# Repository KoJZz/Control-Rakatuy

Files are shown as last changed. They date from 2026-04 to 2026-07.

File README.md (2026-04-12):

# Control-Rakatuy

Repository Control Rakata

## Struktur Folder

* **.git/**: Git configuration (Do not modify)
* **Hardware/**: KiCad PCB layout and schematic files. Nanti buat folder baru aja per project
* **Firmware/**: Firmware yang dipake
* **Docs/**: Documentation
* **Exports/**: (Gerbers, BOM, and PDF schematics)
* **testing/**: ngetes repo

---

### Cloning to a New Machine
To pull this repository into a new local folder:
```bash
git clone https://github.com/KoJZz/Control-Rakatuy

```
### Upload konten baru
```bash
git pull origin main # pull updatean terbaru dari repo
git add . # add file terbaru yang udah dibuat
git commit -m "Update: [Component Name] - Added power stage layout" # commiting
git push origin main # push ke repo

```

### Video tutorial version control
https://www.youtube.com/watch?v=YCKeqBlQyJQ

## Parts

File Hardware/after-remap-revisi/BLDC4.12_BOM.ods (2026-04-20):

Part | Value | Package | Description | Qty | Place (YES/NO) | Distributor | Order Number | Comment
U1 |  | LQFP-64 | STM32F4 MCU | 1 | YES | MOUSER | 511-STM32F405RGT6
U2 |  | SOT-223-3 | VREG | 1 | YES | MOUSER | 579-TC2117-3.3VDBTR
U3 |  | HTSSOP-56-PP | MOSFET Driver | 1 | YES | MOUSER | 595-DRV8302DCA
U401 |  | SOIC-8 | CAN Transceiver | 1 | YES | MOUSER | 595-SN65HVD232DR
R1 |  | SM0603 | NTC resistor (temp sensor) | 1 | YES | MOUSER | 81-NCP18XH103F03RB
L1 |  | inductor_smd_8x5mm | Power Inductor | 1 | YES | MOUSER | 652-SDR0805-220ML
X1 |  | USB-UX60R-MB-5ST | Mini-USB | 1 | YES | MOUSER | 798-UX60R-MB-5ST
X2 | 8MHz | Crystal_5x3mm | Crystal 8MHz, 10PPM | 1 | YES | MOUSER | 815-ABM3B-8.0-10-1UT
Q1-Q6 | 60V 240A | D2PAK-7 | MOSFET 60V 240A | 6 | YES | MOUSER | 942-IRFS7530TRL7PP
R53,R54 | 1mOhm | WSLP2726 | Shunt 1mOhm | 2 | YES | MOUSER | 71-WSLP27261L000FEA
D5 | 5V | DO-214AC | TVS diode 5V | 1 | YES | MOUSER | 576-SMAJ5.0A
D4 | 60V 2A | DO-214AA(SMB) | Shottky 60V 2A | 1 | YES | MOUSER | 771-PMEG6020ER-115 | Voltage and current important
C25,C33 | 100uF, 6.3V | c_tant_B | CAP 100u, 6.3V | 2 | YES | MOUSER | 581-TPSB107K006R0400 | Voltage important
C1,C8,C9,C39,C40,C43,C44,C49 | 10uF 50V | SMD1206 | CAP 10u, 50V, 1206 | 8 | YES | MOUSER | 963-UMK316BBJ106ML-T | Voltage important
C37,C51 | 15uF, 100V | SMD-2220 | CAP 15u, 100V, 2220 | 2 | YES | MOUSER | 810-CGA9P3X7S2A156M | Voltage important
C2,C3,C27,C32 | 100nF, 50V | SMD-0603 | CAP 100n, 50V, 0603 | 4 | YES | MOUSER | 581-06035C104JAT2A | Voltage important
C28,C29,C30 | 220nF,25V | SMD-0603 | CAP 220n, 25V, 0603 | 3 | YES | MOUSER | 963-TMK107B7224KA-T | Voltage important
C24,C10,C11,C12,C13,C14,C16,C17,C18,C20,C23,C26,C31,C35,C41,C52,C401 | 2.2uF, 16V | SMD-0603 | CAP 2.2u, 16V, 0603 | 17 | YES | MOUSER | 810-C1608X5R1C225M | Voltage important
P3 |  | MICRO_JST_7 | Micro-JST 7PIN 2mm | 1 | YES | FARNELL | 9491864 | Can be found on ebay (http://www.ebay.com/sch/i.html?_odkw=jst+6+pin+2.0&_osacat=0&_from=R40&_nkw=jst+7+pin+2.0&_sacat=0)
P1,P2 |  | MICRO_JST_6 | Micro-JST 6PIN 2mm | 2 | YES | FARNELL | 9492453 | Can be found on ebay (http://www.ebay.com/sch/i.html?_odkw=jst+7+pin+2.0&_osacat=0&_from=R40&_nkw=jst+6+pin+2.0&_sacat=0)
P101 |  | MICRO_JST_4 | Micro-JST 4PIN 2mm | 1 | YES | FARNELL | 9492437 | Can be found on ebay (http://www.ebay.com/sch/i.html?_odkw=jst+6+pin+2.0&_osacat=0&_from=R40&_nkw=jst+4+pin+2.0&_sacat=0)
C4-C7 | 4.7nF, 50V | SMD-0603 | CAP 4.7n, 50V, 0603 | 4 | YES | MOUSER | 81-GRM39X472J50D
C34, C36 | 2.2nF, 50V | SMD-0603 | CAP 2.2n, 50V, 0603 | 2 | YES | MOUSER | 81-GRM39X222J50D
C15,C38 | 15pF, 100V | SMD-0603 | CAP 15p, 100V, 0603 | 2 | YES | MOUSER | 81-GRM1885C2A150JA01
C19 | 120pF, 50V | SMD-0603 | CAP 120p, 50V, 0603 | 1 | YES | MOUSER | 81-GRM39C121J50
C21 | 6.8nF, 50V | SMD-0603 | CAP 6.8n, 50V, 0603 | 1 | YES | MOUSER | 81-GRM18R71H682KA01J
C22 | 22nF, 50V | SMD-0603 | CAP 22n, 50V, 0603 | 1 | YES | MOUSER | 81-GRM18F51H223ZA01D
D1 |  | SMD-0603 | LED Green, 0603 | 1 | YES | MOUSER | 859-LTST-C191KGKT
D2 |  | SMD-0603 | LED Red, 0603 | 1 | YES | MOUSER | 859-LTST-C191KRKT
D3 |  | SMD-0603 | LED Blue, 0603 | 1 | YES | MOUSER | 720-LBQ39GN1P1351
R28,R29,R34,R35,R42,R43 | 4.7ohm | SMD-0603 | R 4.7ohm, 0603 | 6 | YES | MOUSER | 660-RK73H1JTTD4R70F
R37,R38,R48-R51,R401 | 100ohm | SMD-0603 | R 100ohm, 0603 | 7 | YES | MOUSER | 660-RK73H1JTTD1000F
R4,R5,R11,R12,R13,R22,R24,R27,R33 | 2.2kOhm | SMD-0603 | R 2.2k, 0603 | 9 | YES | MOUSER | 660-RK73H1JTTD2201F
R18 | 3.3kOhm | SMD-0603 | R 3.3k, 0603 | 1 | YES | MOUSER | 660-RK73H1JTTD3301F
R2,R7,R8,R9,R10,R20,R402 | 10kOhm | SMD-0603 | R 10k, 0603 | 7 | YES | MOUSER | 660-RK73H1JTTD1002F
R19 | 15kOhm | SMD-0603 | R 15k, 0603 | 1 | YES | MOUSER | 660-RK73H1JTTD1502F
R17 | 18kOhm | SMD-0603 | R 18k, 0603 | 1 | YES | MOUSER | 660-RK73H1JTTD1802F
R3,R23,R26,R30,R32,R36,R46 | 39kOhm | SMD-0603 | R 39k, 0603 | 7 | YES | MOUSER | 667-ERJ-3EKF3902V
R21 | 220kOhm | SMD-0603 | R 220k, 0603 | 1 | YES | MOUSER | 660-RK73H1JTTD2203F
R25 | 1MOhm | SMD-0603 | R 1M, 0603 | 1 | YES | MOUSER | 660-RK73H1JTTD1004F
R103, R104 | 22ohm | SMD-0603 | R 22R, 0603 | 2 | YES | MOUSER | 660-RK73H1JTTD22R0F
R6 |  |  |  | 0 | NO |  |  | Do not mount
1PIN,1PIN |  |  |  | 0 | NO |  |  | Do not mount
K1 |  |  |  | 0 | NO |  |  | Do not mount
P5,P5,P6,P7,P9 |  |  |  | 0 | NO |  |  | Do not mount
G*** |  |  |  | 0 | NO |  |  | Do not mount

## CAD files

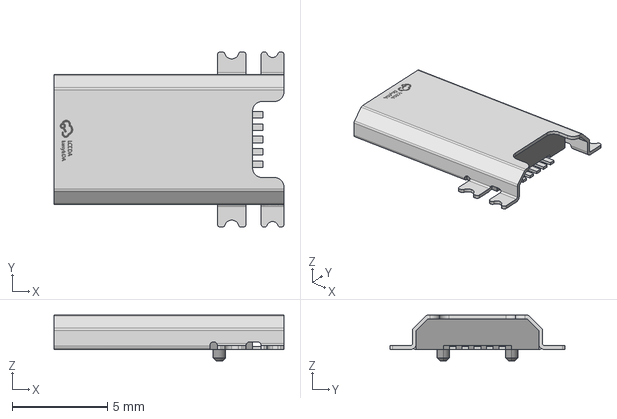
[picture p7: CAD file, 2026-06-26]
Hardware/after-remap-revisi/EASYEDA_MODELS/MICRO-USB-SMD_MICROUSB-5P-M.step
12.1 x 9.23 x 2.40 mm

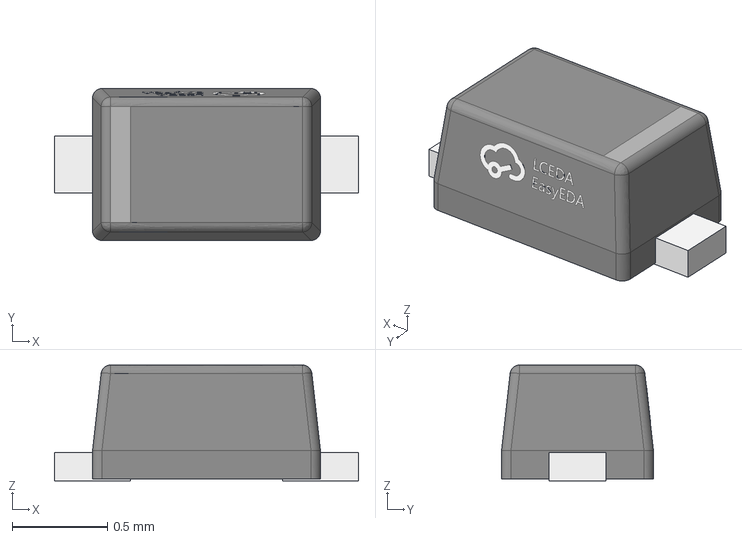
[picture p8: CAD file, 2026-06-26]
Hardware/after-remap-revisi/EASYEDA_MODELS/SOD-523F_L1.2-W0.8-H0.6-LS1.6.step
1.60 x 0.8 x 0.61 mm

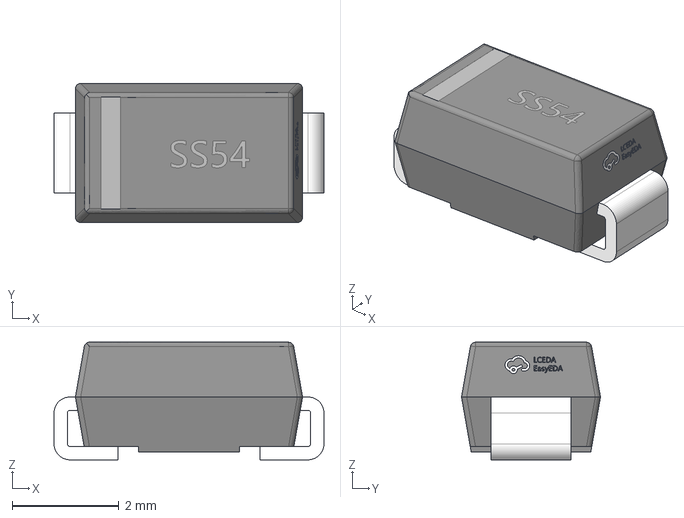
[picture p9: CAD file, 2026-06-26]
Hardware/after-remap-revisi/EASYEDA_MODELS/SMA_L4.2-W2.6-LS5.1-RD.step
5.05 x 2.60 x 2.20 mm

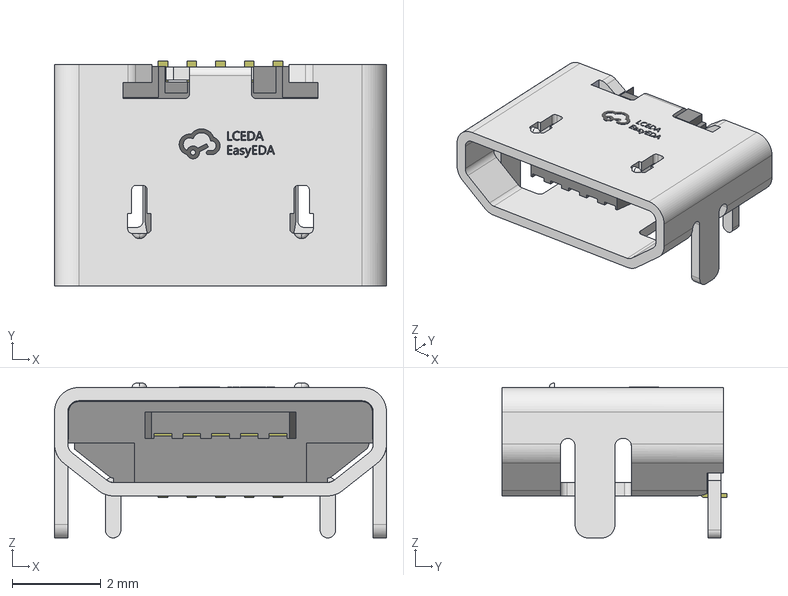
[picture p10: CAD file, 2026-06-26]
Hardware/after-remap-revisi/EASYEDA_MODELS/MICRO-USB-SMD_HX-USB-MICRO-XNJ-JB.step
7.50 x 5.08 x 3.50 mm

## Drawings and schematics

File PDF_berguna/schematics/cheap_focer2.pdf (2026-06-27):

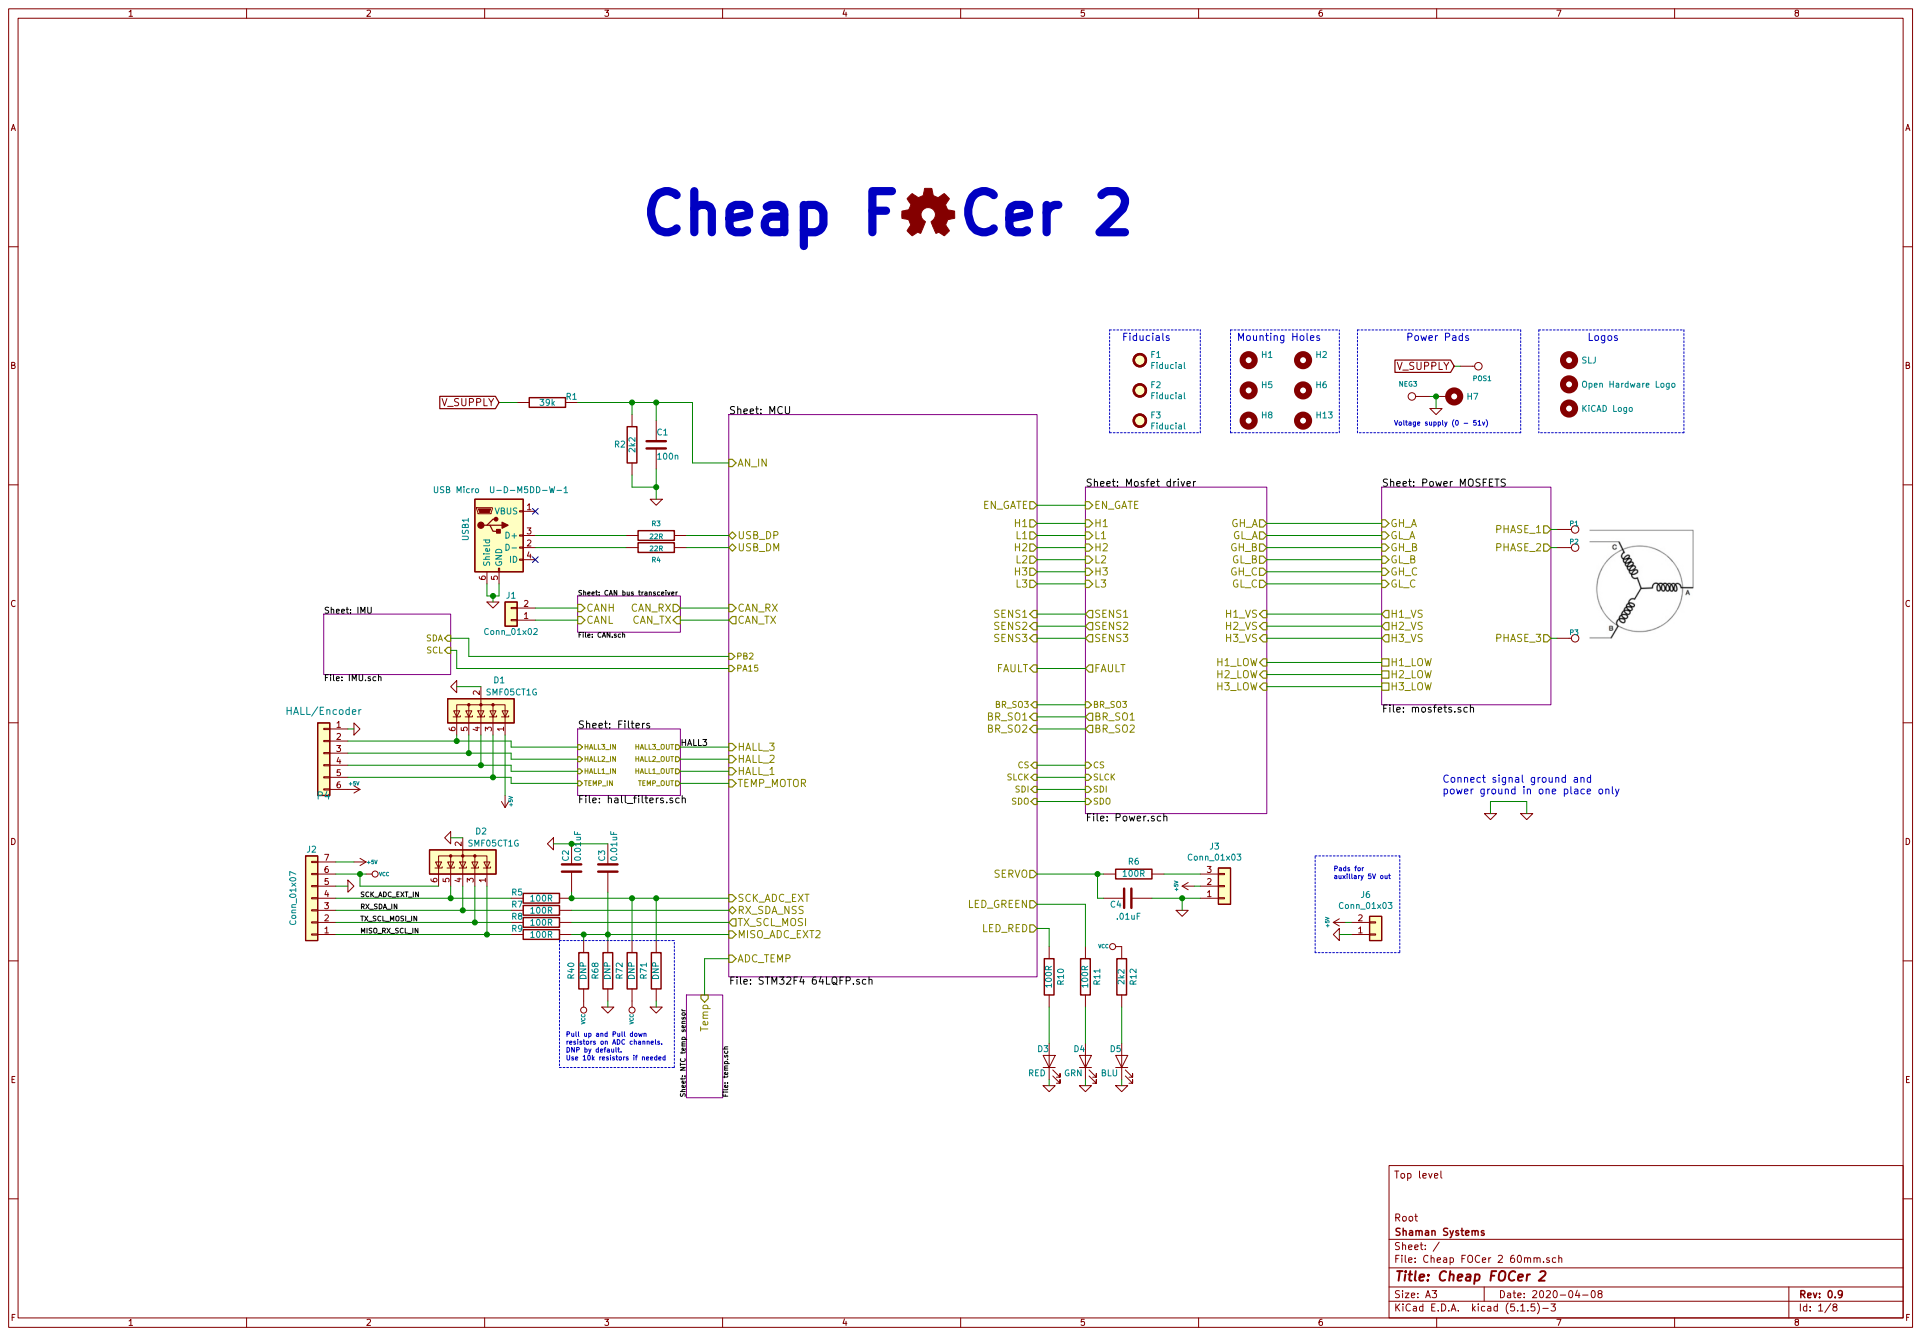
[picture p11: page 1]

power ground in one place only

Pull up and Pull down resistors on ADC channels. DNP by default. Use 10k resistors if needed

File: Cheap FOCer 2 60mm.sch Sheet: / Shaman Systems Root Top level

Id: 1/8 Title: Cheap FOCer 2

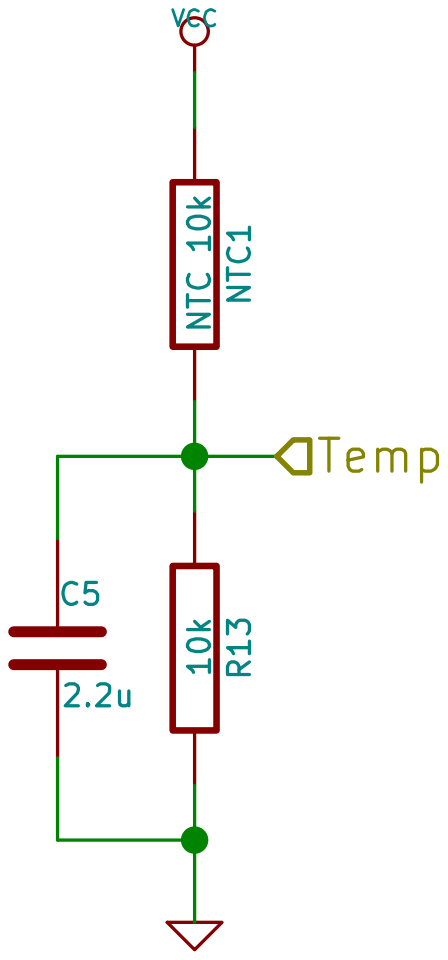
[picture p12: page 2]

Shaman Systems Root Top level 10k R13 C5

Sheet: /NTC temp sensor/
File: temp.sch
Id: 2/8 Title: Cheap FOCer 2

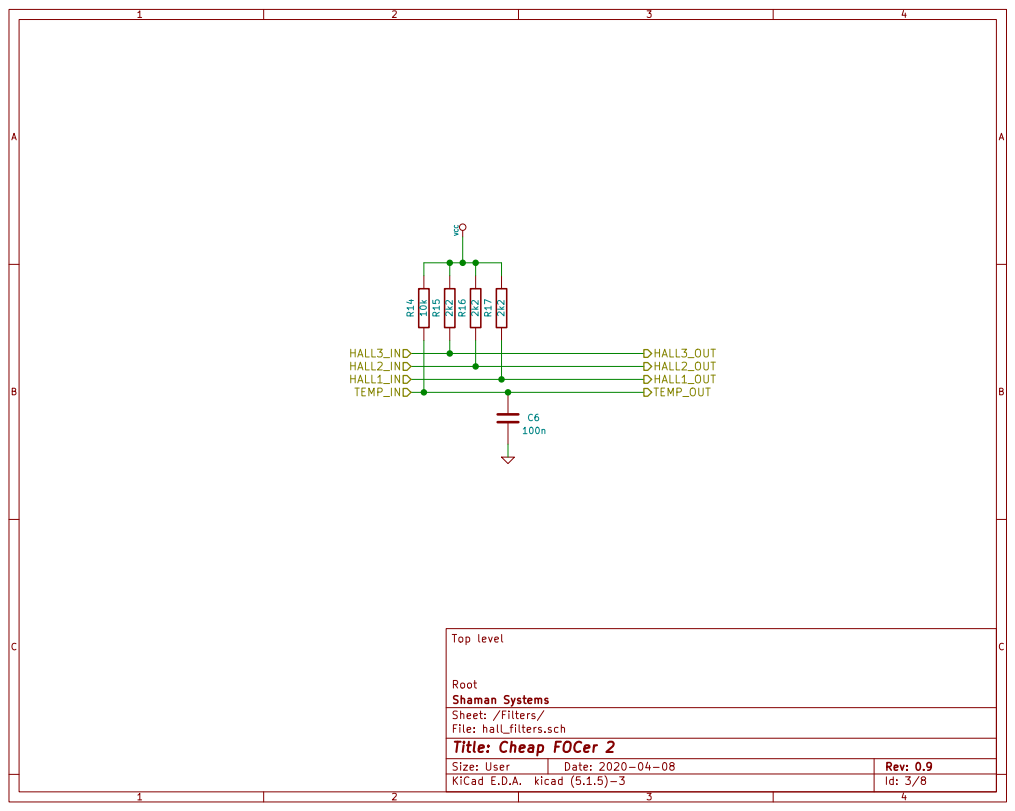
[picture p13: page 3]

Id: 3/8 Title: Cheap FOCer 2

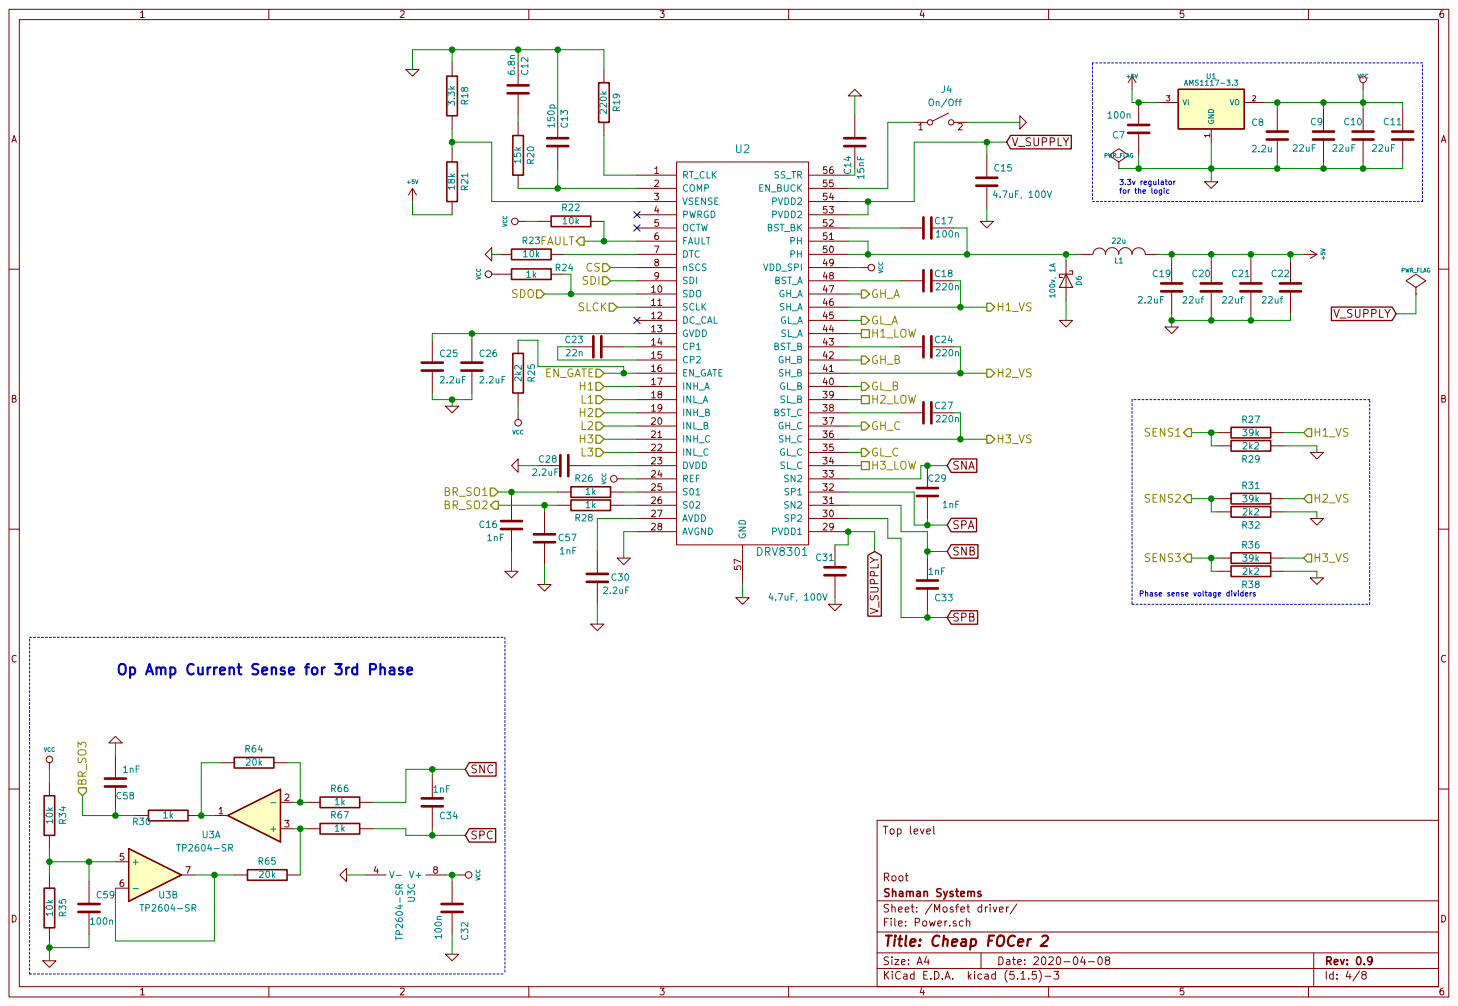
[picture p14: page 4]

for the logic Phase sense voltage dividers Op Amp Current Sense for 3rd Phase

File: Power.sch Sheet: /Mosfet driver/ Shaman Systems Root Top level VCC R67

Id: 4/8 Title: Cheap FOCer 2

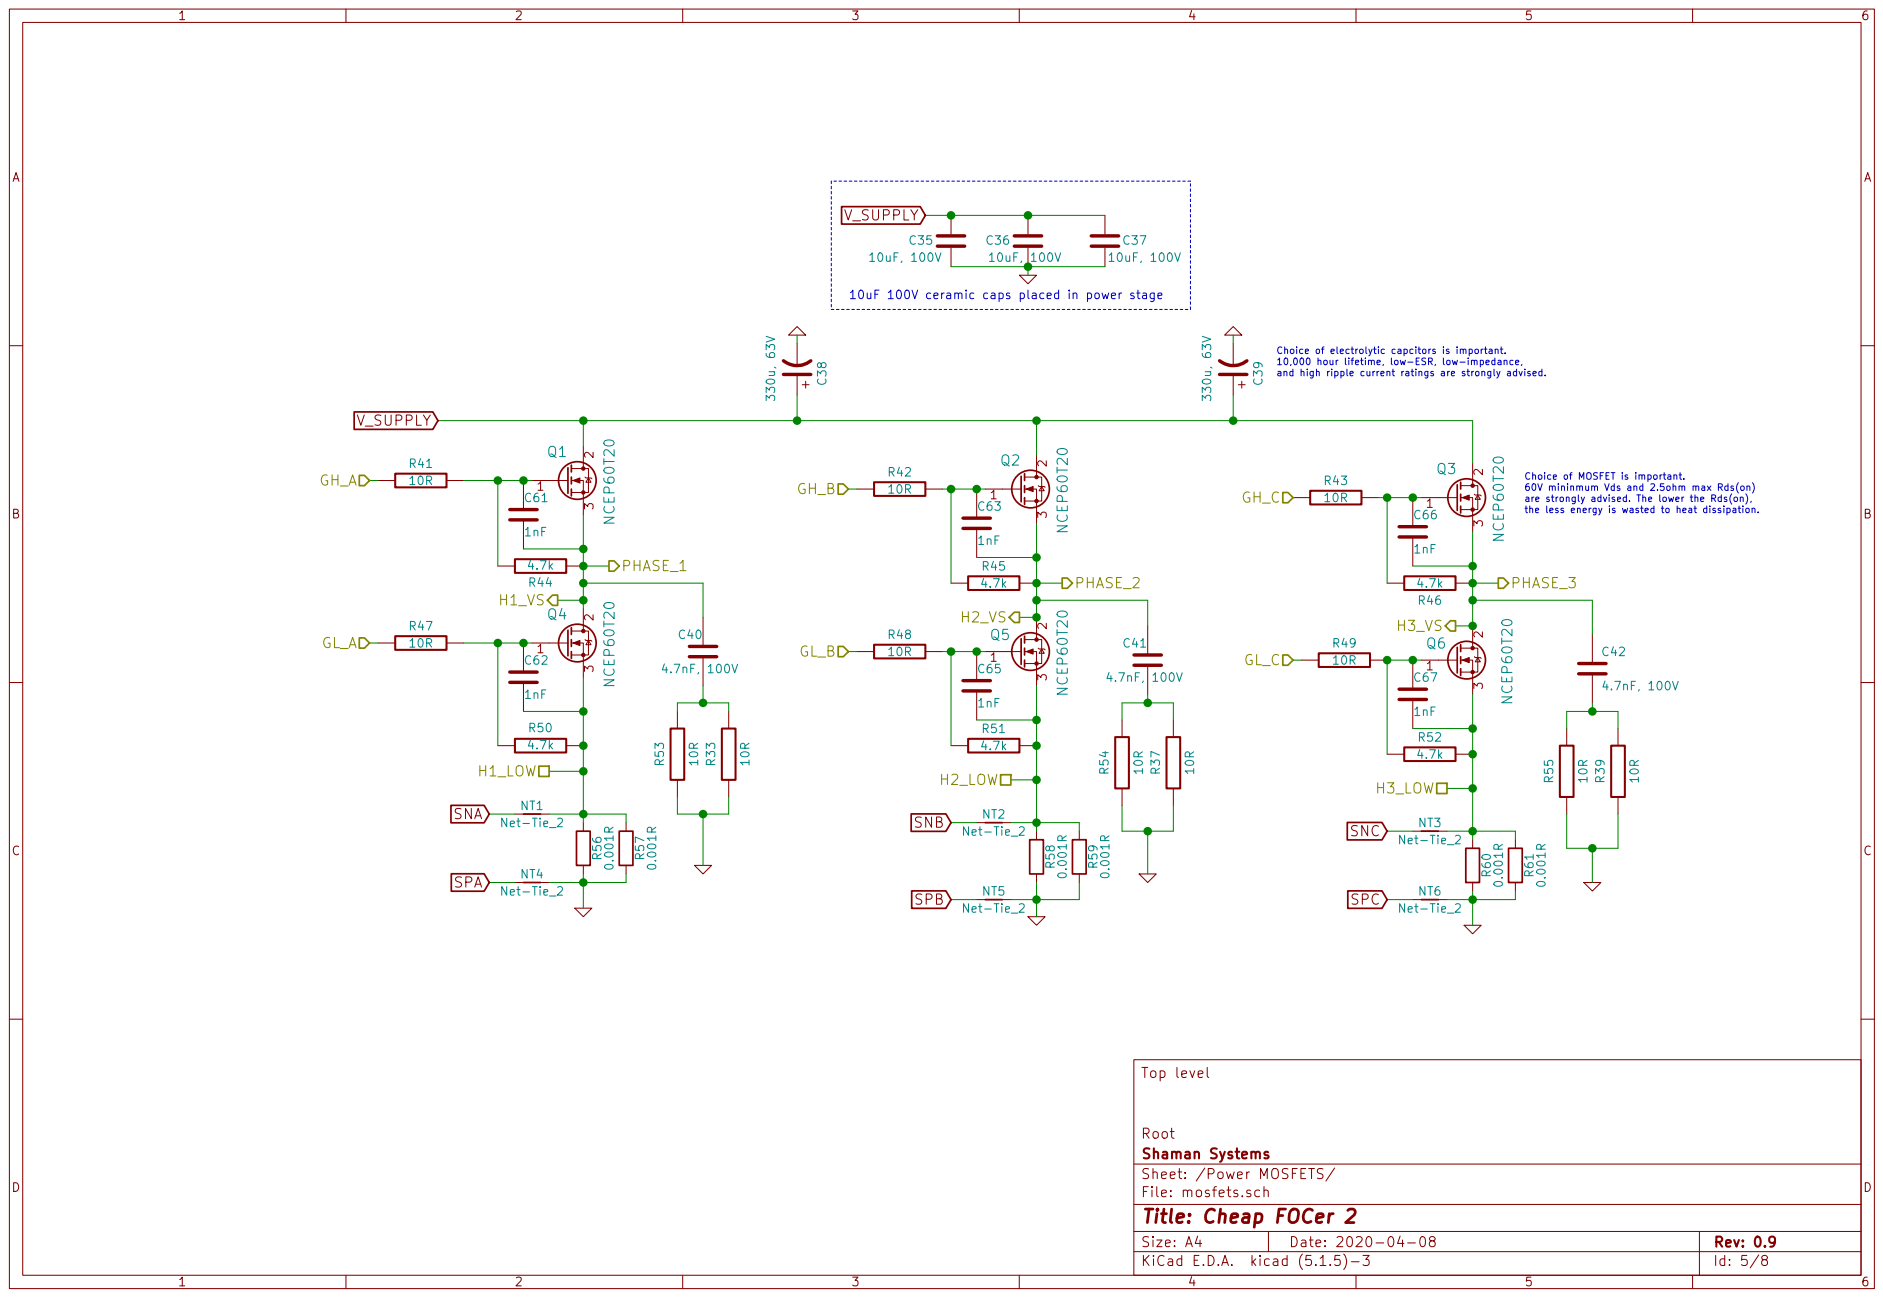
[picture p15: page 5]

the less energy is wasted to heat dissipation.

Id: 5/8 Title: Cheap FOCer 2

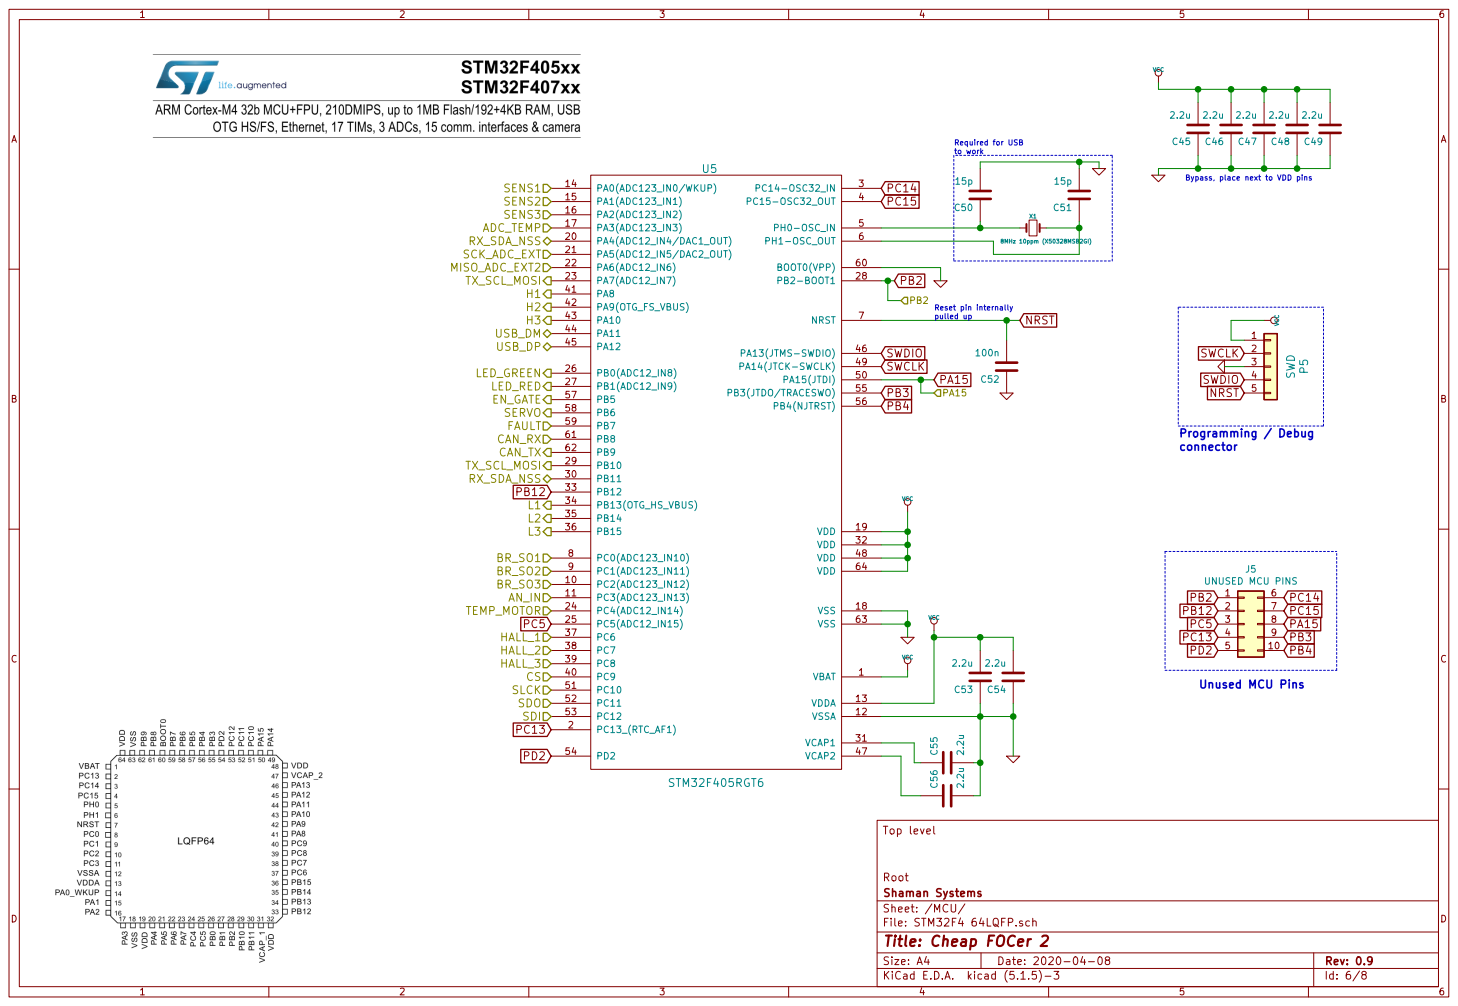
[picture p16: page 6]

Bypass, place next to VDD pins Required for USB

connector Reset pin internally pulled up

Id: 6/8 Title: Cheap FOCer 2

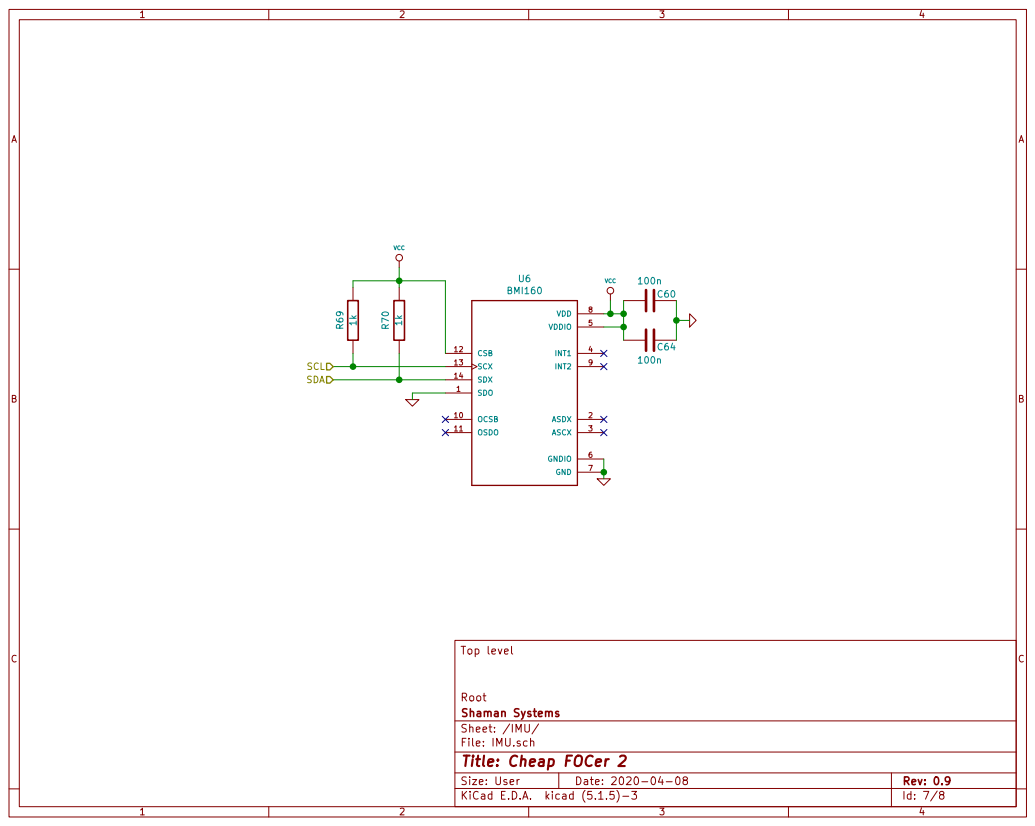
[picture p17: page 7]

Id: 7/8 Title: Cheap FOCer 2

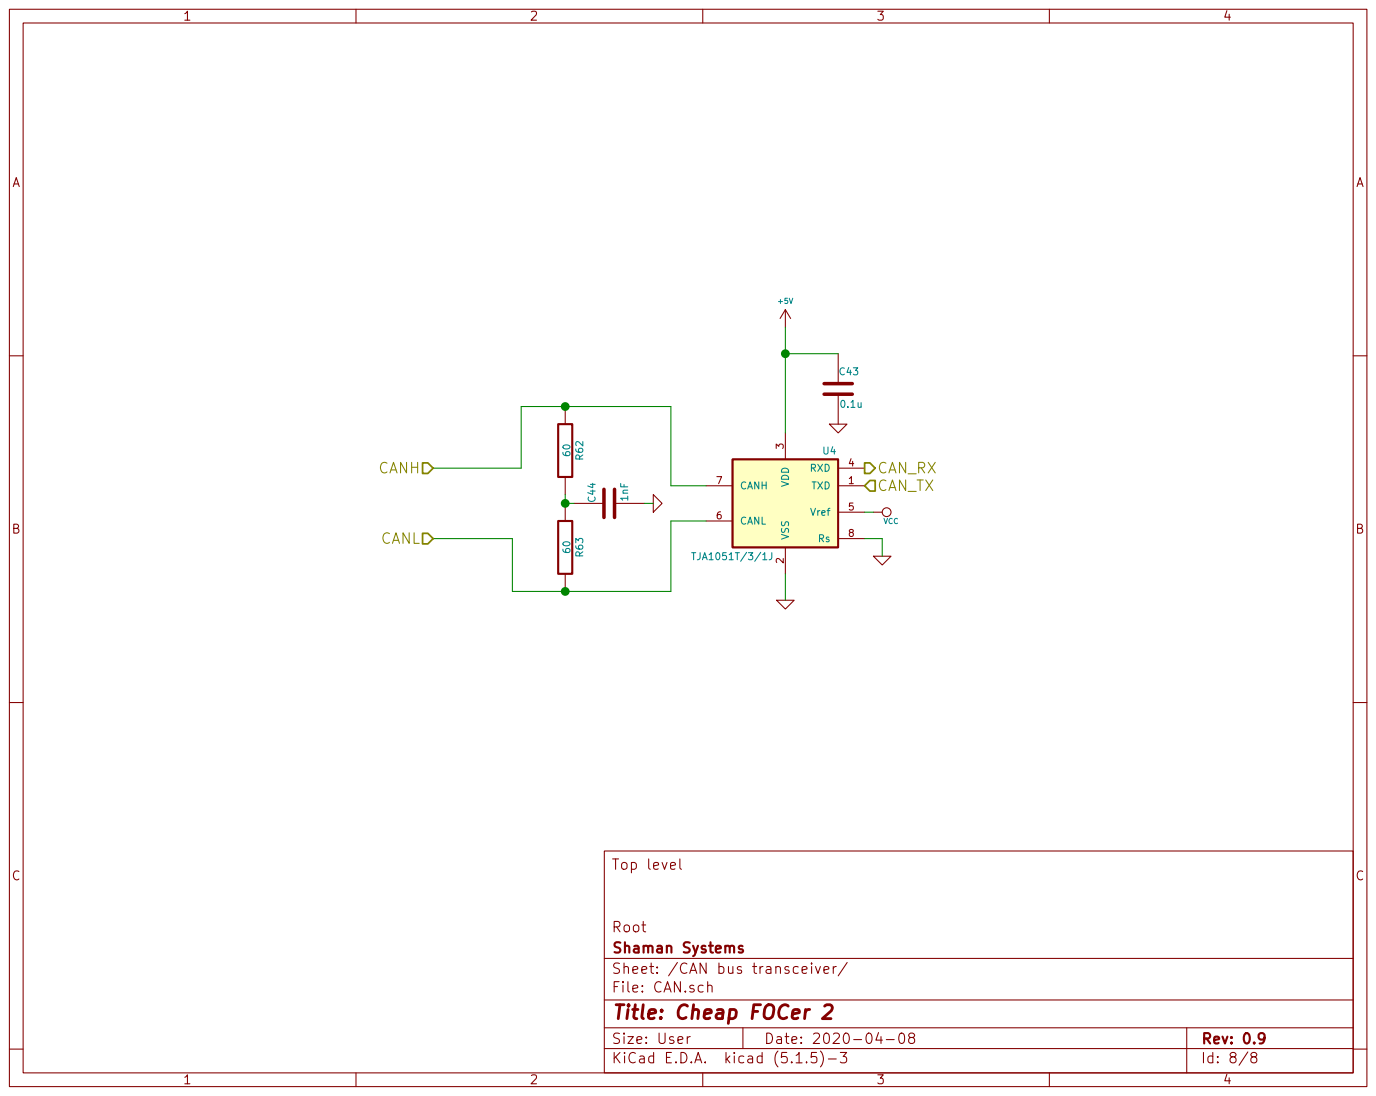
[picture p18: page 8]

3 RXD 4 Vref 5 CANL 6 CANH 7 Rs 8 U4 TJA1051T/3/1J CAN_RX

Id: 8/8 Title: Cheap FOCer 2

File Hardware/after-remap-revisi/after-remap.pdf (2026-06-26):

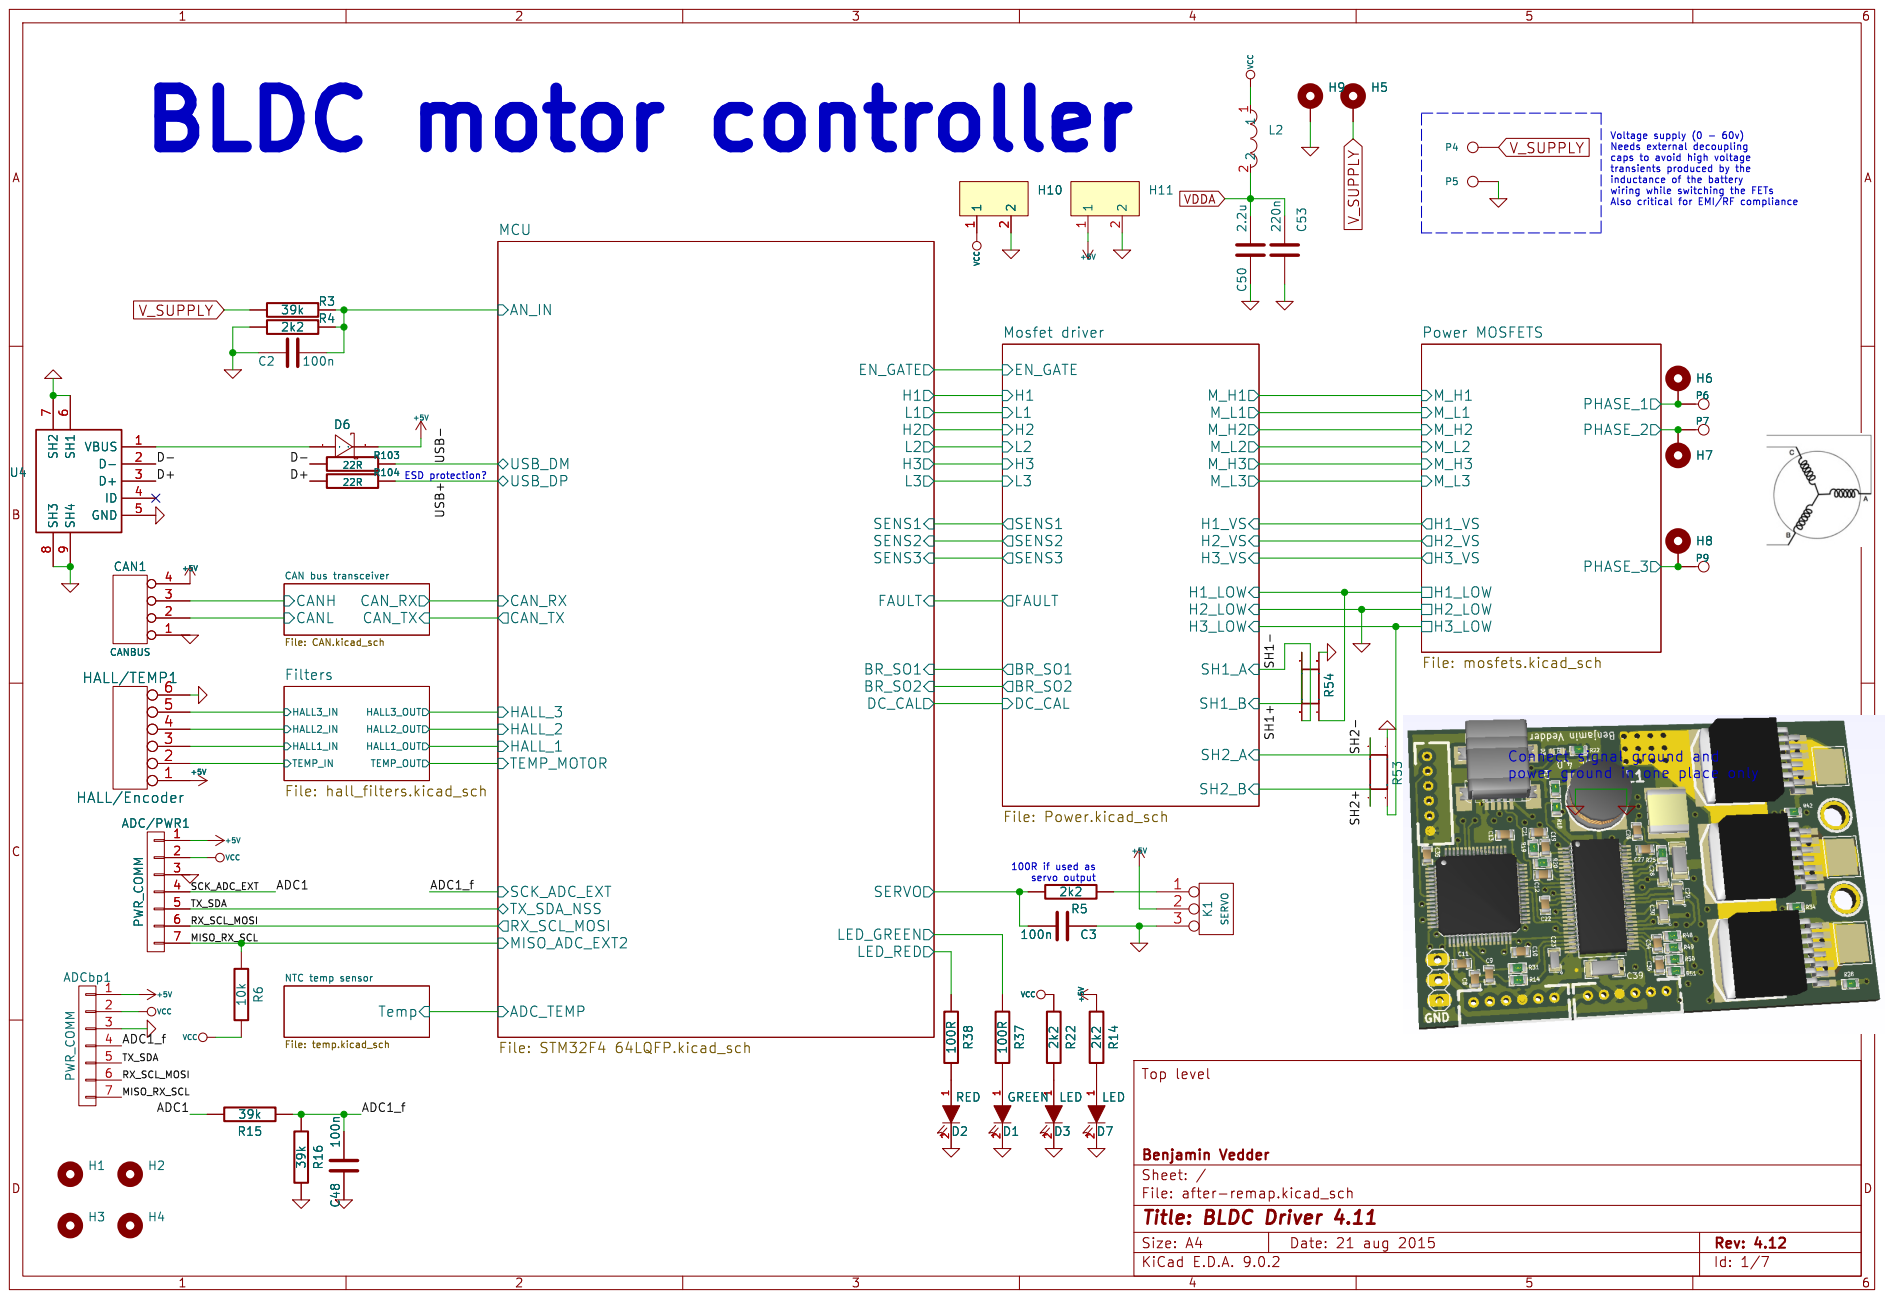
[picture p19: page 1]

SH2_B Mosfet driver File: Power.kicad_sch

caps to avoid high voltage

power ground in one place only

Id: 1/7 Title: BLDC Driver 4.11

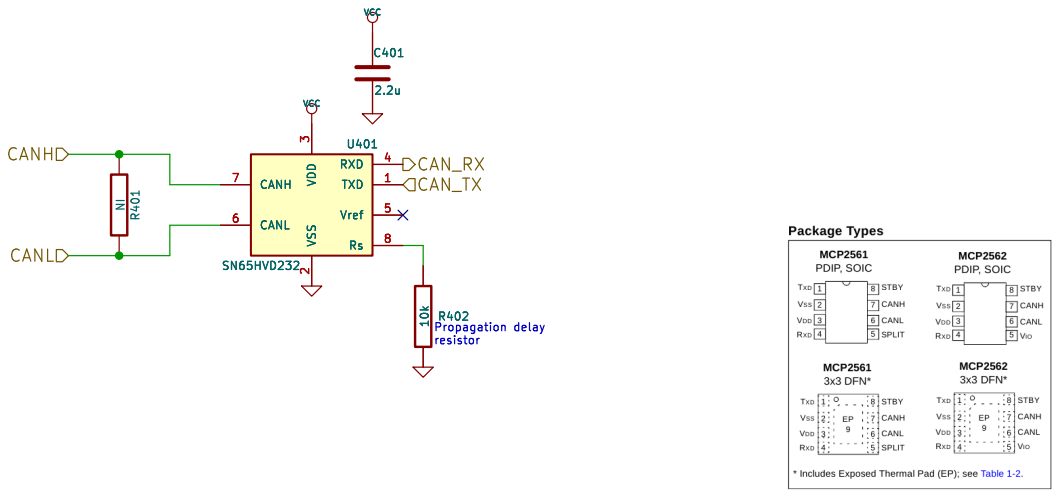
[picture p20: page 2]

Id: 2/7 Title: BLDC Driver 4.11

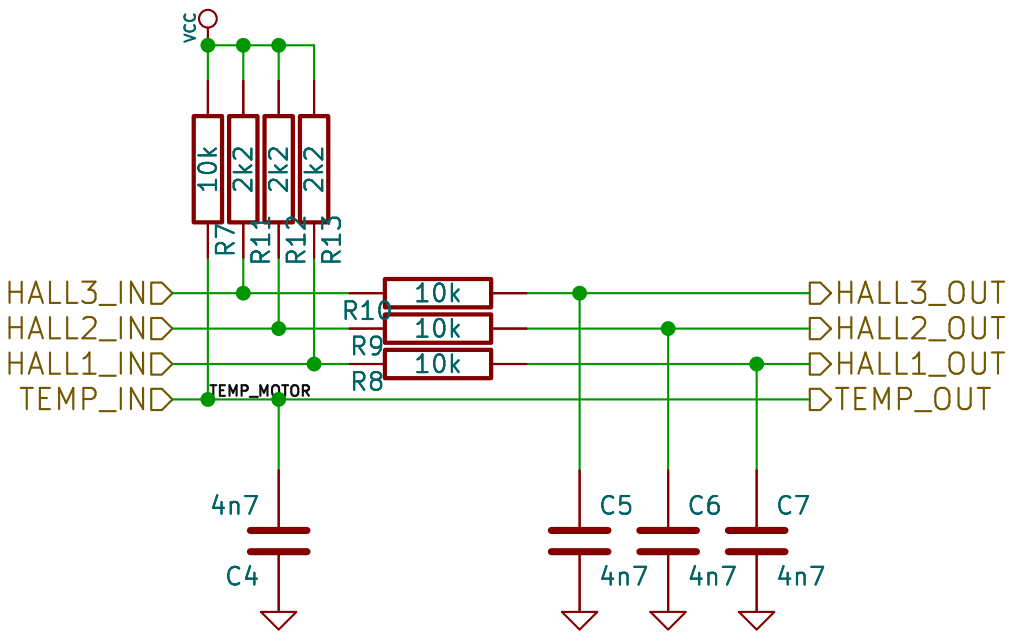
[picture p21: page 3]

File: hall_filters.kicad_sch Sheet: /Filters/ Benjamin Vedder C7

Id: 3/7 Title: BLDC Driver 4.11

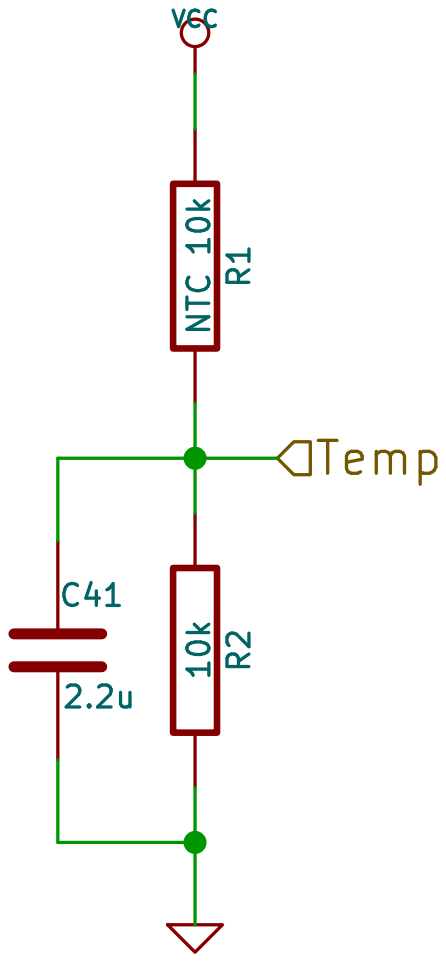
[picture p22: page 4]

File: temp.kicad_sch Sheet: /NTC temp sensor/ Benjamin Vedder R1 NTC 10k VCC10k R2 C41

Id: 4/7 Title: BLDC Driver 4.11


Bypass, place next to VDD pins Required for USB

connector Reset pin internally pulled up C32

Id: 5/7 Title: BLDC Driver 4.11


voltage at each phase

Id: 6/7 Title: BLDC Driver 4.11


Id: 7/7 Title: BLDC Driver 4.11

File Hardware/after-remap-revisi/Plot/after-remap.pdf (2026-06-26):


SH2_B Mosfet driver File: Power.kicad_sch

caps to avoid high voltage

CAN bus transceiver File: CAN.kicad_sch HALL3_IN
CANH
CANL

power ground in one place only R54

Id: 1/7 Title: BLDC Driver 4.11


Id: 2/7 Title: BLDC Driver 4.11


File: hall_filters.kicad_sch Sheet: /Filters/ Benjamin Vedder C6

Id: 3/7 Title: BLDC Driver 4.11


File: temp.kicad_sch Sheet: /NTC temp sensor/ Benjamin Vedder R1 NTC 10k VCC10k R2 C41

Id: 4/7 Title: BLDC Driver 4.11


Bypass, place next to VDD pins Required for USB

connector Reset pin internally pulled up C32

Id: 5/7 Title: BLDC Driver 4.11


voltage at each phase

Id: 6/7 Title: BLDC Driver 4.11


Id: 7/7 Title: BLDC Driver 4.11

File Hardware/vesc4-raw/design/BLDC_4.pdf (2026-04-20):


Voltage supply (0 - 60v) Needs external decoupling
caps to avoid high voltage
transients produced by the

power ground in one place only

File: BLDC_4.sch Sheet: / Benjamin Vedder

Id: 1/7 Title: BLDC Driver 4.11


39k V_SUPPLY
File: mosfets.sch Sheet: /Power MOSFETS/ Benjamin Vedder R46

Id: 2/7 Title: BLDC Driver 4.11


Sheet: /NTC temp sensor/
File: temp.sch
Id: 3/7 Title: BLDC Driver 4.11


3 RXD 4 Vref 5 CANL 6 CANH 7 Rs 8 U401 SN65HVD232

File: CAN.sch Sheet: /CAN bus transceiver/ Benjamin Vedder

Id: 4/7 Title: BLDC Driver 4.11


Id: 5/7 Title: BLDC Driver 4.11


Id: 6/7 Title: BLDC Driver 4.11


MCU must sense the
voltage at each phase

File: Power.sch Sheet: /Mosfet driver/ Benjamin Vedder

Id: 7/7 Title: BLDC Driver 4.11

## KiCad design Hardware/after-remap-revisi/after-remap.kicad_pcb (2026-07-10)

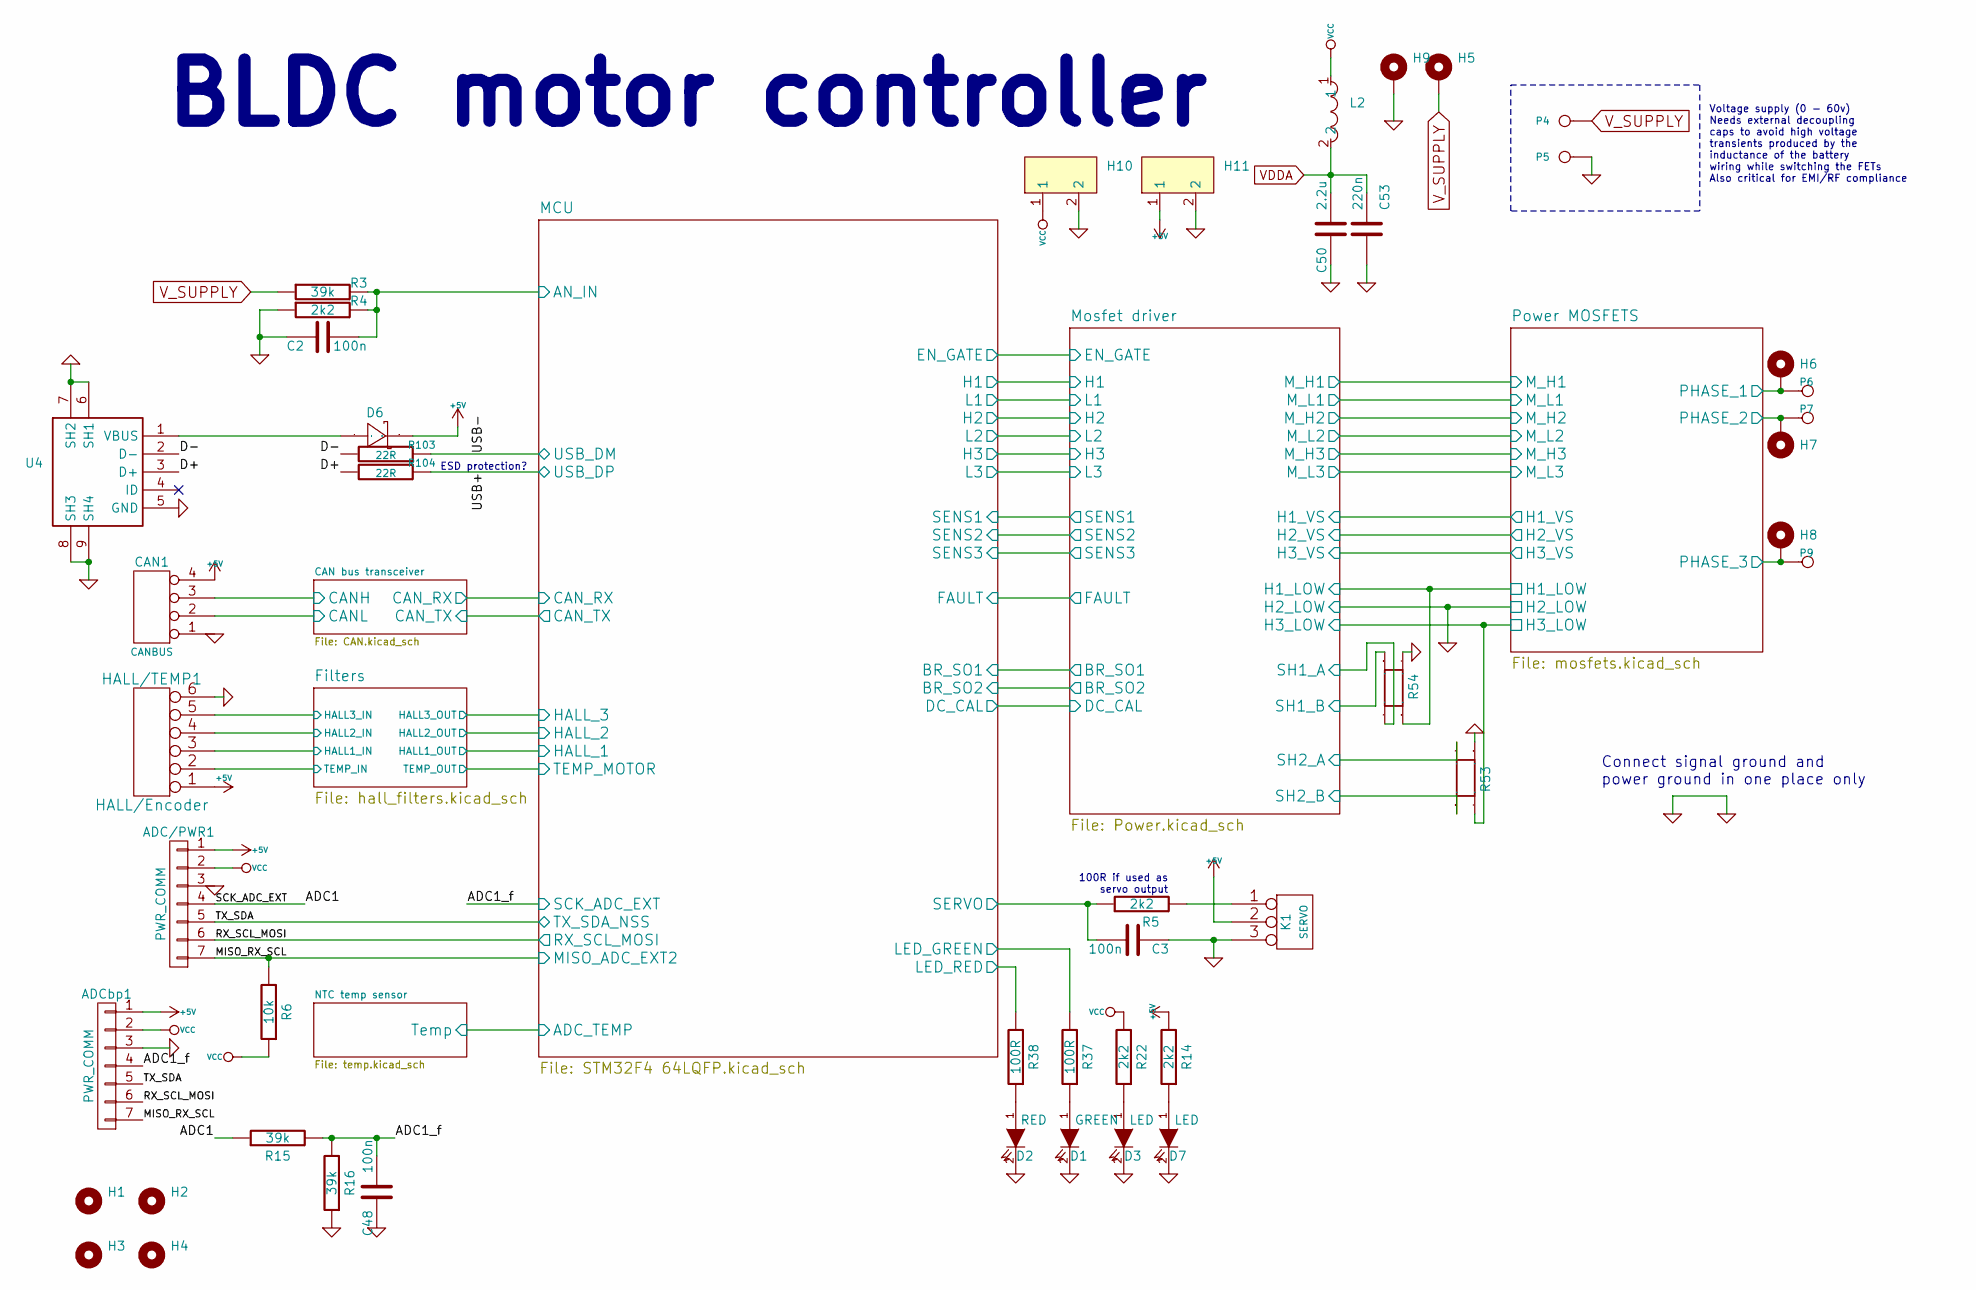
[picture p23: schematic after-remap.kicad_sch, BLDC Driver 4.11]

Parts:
ADC/PWR1: PWR_COMM; CONN-TH_B7B-PH-K-S-LF-SN
ADCbp1: PWR_COMM; CONN-TH_B7B-PH-K-S-LF-SN
C2, C3: 100n; C0603; LCSC C14663
C48: 100n; C0603; LCSC C21122
C50: 2.2u; C0603; LCSC C23630
C53: 220n; C0603; LCSC C21120
CAN1: CANBUS; CONN-TH_B4B-PH-K-S
D1: GREEN; LED0603-R-RD_WHITE; LCSC C125098
D2: RED; LED0603-R-RD_WHITE; LCSC C125099
D3, D7: LED; LED0603-R-RD_WHITE; LCSC C2290
D6: SOD-123_L2.8-W1.8-LS3.7-RD; Manufacturer Part SS110; LCSC Part Name 电压:100V 电流:1A
H1, H2, H3, H4, H6, H7, H8: MountingHole; MountingHole_3.2mm_M3_DIN965_Pad
H5, H9: MountingHole_Pad; MountingHole_3.2mm_M3_DIN965_Pad
H10, H11: Header-Male-2.54_1x2; HDR-TH_2P-P2.54-V-M-1; MPN 826629-2; LCSC Part C86471
HALL/TEMP1: HALL/Encoder; CONN-TH_B6B-PH-K-S
K1: SERVO; pinhead-1X03
L2: BLM18AG601SN1D; L0603; MPN BLM18AG601SN1D; LCSC Part C19330
P4: IN+; PAD
P5: IN-; PAD
P6: MOTOR1; PAD
P7: MOTOR2; PAD
P9: MOTOR3; PAD
R3, R15, R16: 39k; R0603; JLC_3DModel 6bd5cd867e9542ebae21caaf5d2d4c4d
R4, R5, R14, R22: 2k2; R0603; JLC_3DModel 6bd5cd867e9542ebae21caaf5d2d4c4d
R6: 10k; R0603; JLC_3DModel 6bd5cd867e9542ebae21caaf5d2d4c4d
R37, R38: 100R; R0603; JLC_3DModel 6bd5cd867e9542ebae21caaf5d2d4c4d
R53, R54: WSLP27262L000FEA; R2726; Manufacturer Part WSLP27262L000FEA; JLC_3DModel 76bc509a5511445c8d320e01eb58c99c
R103, R104: 22R; R0603; JLC_3DModel 6bd5cd867e9542ebae21caaf5d2d4c4d
U4: MICROQTJ; MICRO-USB-SMD_MICROQTJ-5P; Manufacturer Part MicroQTJ; LCSC C404968

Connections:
+5V: ADC/PWR1.1, ADCbp1.1, CAN1.4, D6.1 (K), H11.1, HALL/TEMP1.1, K1.2 (PM), R14.2; also elsewhere on the board
/ADC1: ADC/PWR1.4, R15.1
/ADC1_f: ADCbp1.4, C48.1, R15.2, R16.2; also elsewhere on the board
/CAN bus transceiver/CANH: CAN1.3; also elsewhere on the board
/CAN bus transceiver/CANL: CAN1.2; also elsewhere on the board
/D+: R104.2, U4.3 (D+)
/D-: R103.2, U4.2 (D-)
/Filters/HALL1_IN: HALL/TEMP1.3; also elsewhere on the board
/Filters/HALL2_IN: HALL/TEMP1.4; also elsewhere on the board
/Filters/HALL3_IN: HALL/TEMP1.5; also elsewhere on the board
/Filters/TEMP_MOTOR: HALL/TEMP1.2; also elsewhere on the board
/MCU/AN_IN: C2.2, R3.2, R4.2; also elsewhere on the board
/MCU/LED_GREEN: R37.2; also elsewhere on the board
/MCU/LED_RED: R38.2; also elsewhere on the board
/MCU/SERVO: C3.2, R5.1; also elsewhere on the board
/MISO_RX_SCL: ADC/PWR1.7, ADCbp1.7, R6.2; also elsewhere on the board
/Mosfet driver/SH1_A: R54.2; also elsewhere on the board
/Mosfet driver/SH1_B: R54.1; also elsewhere on the board
/Mosfet driver/SH2_A: R53.2; also elsewhere on the board
/Mosfet driver/SH2_B: R53.1; also elsewhere on the board
/Power MOSFETS/Q1-s_Q2-d: H6.1, P6.1; also elsewhere on the board
/Power MOSFETS/Q2-s: R54.4; also elsewhere on the board
/Power MOSFETS/Q3-s_Q4-d: H7.1, P7.1; also elsewhere on the board
/Power MOSFETS/Q5-s_Q6-d: H8.1, P9.1; also elsewhere on the board
/Power MOSFETS/Q6-s: R53.3; also elsewhere on the board
/RX_SCL_MOSI: ADC/PWR1.6, ADCbp1.6; also elsewhere on the board
/TX_SDA: ADC/PWR1.5, ADCbp1.5; also elsewhere on the board
/USB+: R104.1; also elsewhere on the board
/USB-: R103.1; also elsewhere on the board
GND: ADC/PWR1.3, ADCbp1.3, C2.1, C3.1, C48.2, C50.2, C53.2, CAN1.1, D1.2 (K), D2.2 (K), D3.2 (K), D7.2 (K), H9.1, H10.2, H11.2, HALL/TEMP1.6, K1.3, P5.1, R4.1, R16.1, R53.4, R54.3, U4.5 (GND), U4.6 (SH1), U4.7 (SH2), U4.8 (SH3), U4.9 (SH4); also elsewhere on the board
unnamed: D1.1 (A), R37.1
unnamed: D2.1 (A), R38.1
unnamed: D3.1 (A), R22.1
unnamed: D6.2 (A), U4.1 (VBUS)
unnamed: D7.1 (A), R14.1
unnamed: K1.1, R5.2
VCC: ADC/PWR1.2, ADCbp1.2, H10.1, L2.1, R6.1, R22.2; also elsewhere on the board
VDDA: C50.1, C53.1, L2.2; also elsewhere on the board
V_SUPPLY: H5.1, P4.1, R3.1; also elsewhere on the board

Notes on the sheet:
BLDC motor controller
Voltage supply (0 - 60v) Needs external decoupling caps to avoid high voltage transients produced by the inductance of the battery wiring while switching the FETs Also critical for EMI/RF compliance
Connect signal ground and power ground in one place only
ESD protection?
100R if used as servo output

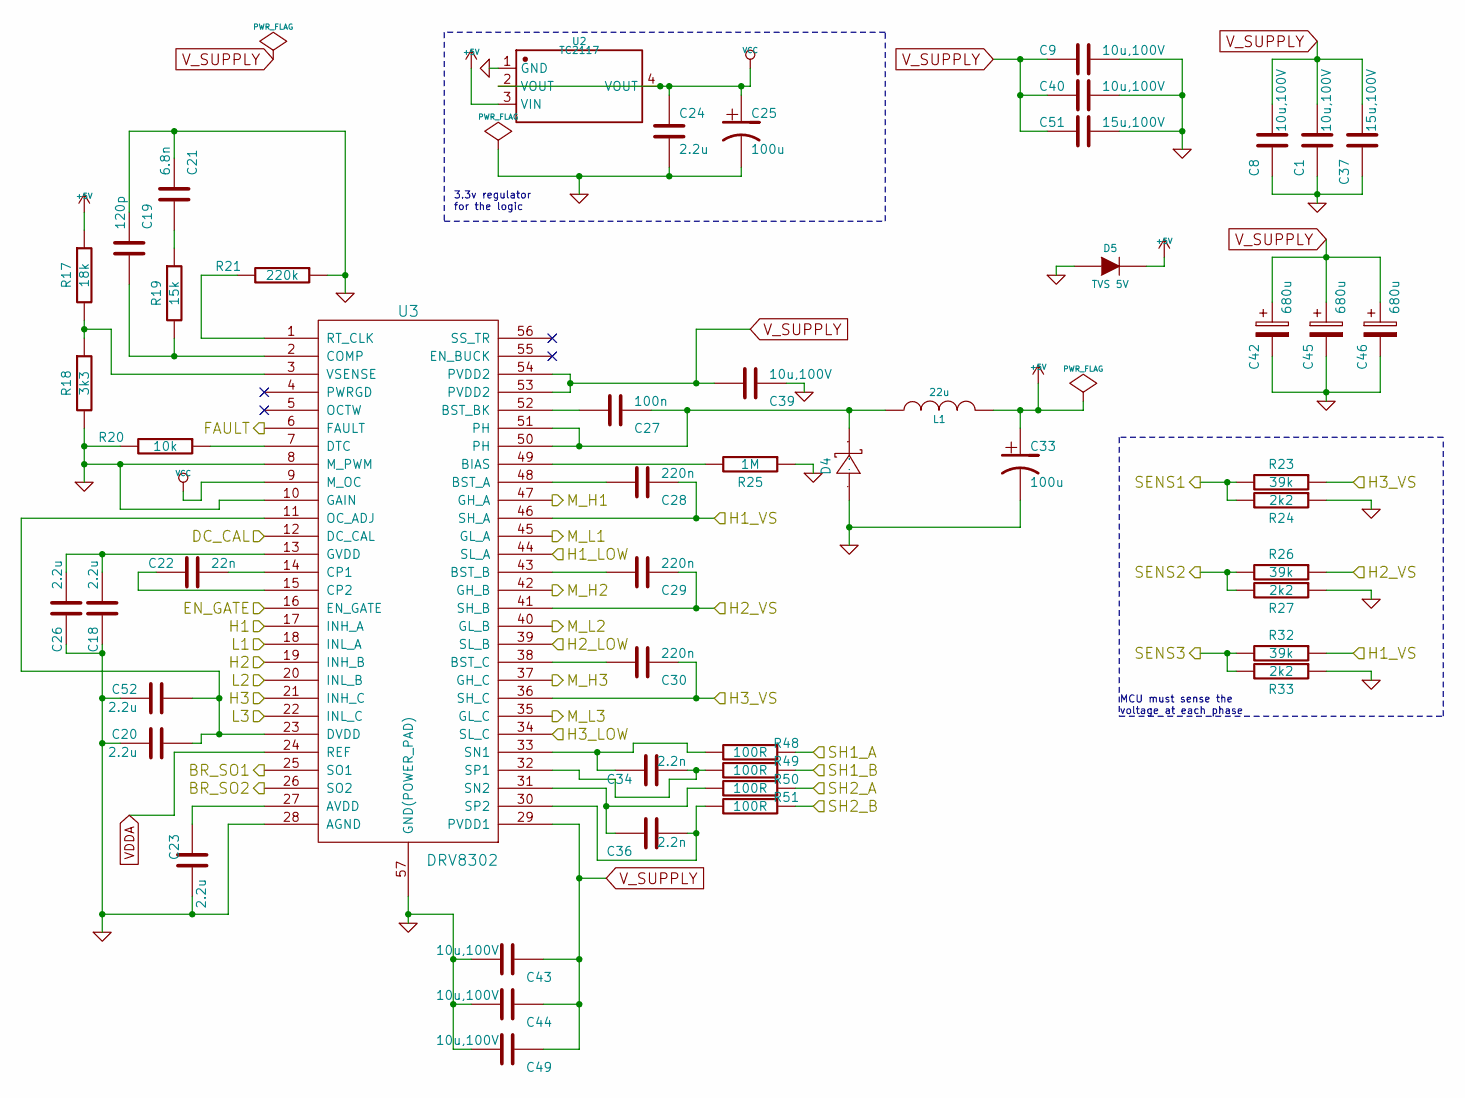
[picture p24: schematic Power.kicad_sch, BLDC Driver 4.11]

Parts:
C1, C8, C39: 10u,100V; C1210; JLC_3DModel ac9b32e974bc448eab36b1293f859dcb
C9, C40, C43, C44, C49: 10u,100V; C1210; LCSC C13585
C18, C20, C23, C24, C26, C52: 2.2u; C0603; LCSC C23630
C19: 120p; C0603; LCSC C107035
C21: 6.8n; C0603; LCSC C1631
C22: 22n; C0603; LCSC C21122
C25, C33: 100u; CAP-SMD_L3.5-W2.8-R-RD; LCSC C2976906
C27: 100n; C0603; LCSC C14663
C28, C29, C30: 220n; C0603; LCSC C21120
C34, C36: 2.2n; SMD-0603_c; LCSC C1604
C37, C51: 15u,100V; C2220; LCSC C361175
C42, C45, C46: 680u; CAP-TH_BD18.0-P7.50-D1.2-FD
D4: SOD-123_L2.8-W1.8-LS3.7-RD; Manufacturer Part SS110; LCSC Part Name 电压:100V 电流:1A
D5: TVS 5V; SOD-123_L2.8-W1.8-LS3.7-RD; LCSC C478011
L1: 22u; IND-SMD_L6.0-W6.0; LCSC C168080
R17: 18k; R0603; JLC_3DModel 6bd5cd867e9542ebae21caaf5d2d4c4d
R18: 3k3; R0603; JLC_3DModel 6bd5cd867e9542ebae21caaf5d2d4c4d
R19: 15k; R0603; JLC_3DModel 6bd5cd867e9542ebae21caaf5d2d4c4d
R20: 10k; R0603; JLC_3DModel 6bd5cd867e9542ebae21caaf5d2d4c4d
R21: 220k; R0603; JLC_3DModel 6bd5cd867e9542ebae21caaf5d2d4c4d
R23, R26, R32: 39k; R0603; JLC_3DModel 6bd5cd867e9542ebae21caaf5d2d4c4d
R24, R27, R33: 2k2; R0603; JLC_3DModel 6bd5cd867e9542ebae21caaf5d2d4c4d
R25: 1M; R0603; JLC_3DModel 6bd5cd867e9542ebae21caaf5d2d4c4d
R48, R49, R50, R51: 100R; R0603; JLC_3DModel 6bd5cd867e9542ebae21caaf5d2d4c4d
U2: TC2117; SOT-223_L6.5-W3.5-P2.30-LS7.0-BR; LCSC C98655
U3: DRV8302; TSSOP-56-PP; LCSC C84672

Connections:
+5V: C33.1, D5.2 (K), L1.2, R17.1, U2.3 (VIN); also elsewhere on the board
/MCU/BR_SO1: U3.25 (SO1); also elsewhere on the board
/MCU/BR_SO2: U3.26 (SO2); also elsewhere on the board
/MCU/DC_CAL: U3.12 (DC_CAL); also elsewhere on the board
/MCU/EN_GATE: U3.16 (EN_GATE); also elsewhere on the board
/MCU/FAULT: U3.6 (FAULT); also elsewhere on the board
/MCU/H1: U3.17 (INH_A); also elsewhere on the board
/MCU/H2: U3.19 (INH_B); also elsewhere on the board
/MCU/H3: U3.21 (INH_C); also elsewhere on the board
/MCU/L1: U3.18 (INL_A); also elsewhere on the board
/MCU/L2: U3.20 (INL_B); also elsewhere on the board
/MCU/L3: U3.22 (INL_C); also elsewhere on the board
/MCU/SENS1: R23.2, R24.2; also elsewhere on the board
/MCU/SENS2: R26.2, R27.2; also elsewhere on the board
/MCU/SENS3: R32.2, R33.2; also elsewhere on the board
/Mosfet driver/M_H1: U3.47 (GH_A); also elsewhere on the board
/Mosfet driver/M_H2: U3.42 (GH_B); also elsewhere on the board
/Mosfet driver/M_H3: U3.37 (GH_C); also elsewhere on the board
/Mosfet driver/M_L1: U3.45 (GL_A); also elsewhere on the board
/Mosfet driver/M_L2: U3.40 (GL_B); also elsewhere on the board
/Mosfet driver/M_L3: U3.35 (GL_C); also elsewhere on the board
/Mosfet driver/SH1_A: R48.1; also elsewhere on the board
/Mosfet driver/SH1_B: R49.1; also elsewhere on the board
/Mosfet driver/SH2_A: R50.1; also elsewhere on the board
/Mosfet driver/SH2_B: R51.1; also elsewhere on the board
/Power MOSFETS/Q1-s_Q2-d: C28.1, R32.1, U3.46 (SH_A); also elsewhere on the board
/Power MOSFETS/Q2-s: U3.44 (SL_A); also elsewhere on the board
/Power MOSFETS/Q3-s_Q4-d: C29.1, R26.1, U3.41 (SH_B); also elsewhere on the board
/Power MOSFETS/Q5-s_Q6-d: C30.1, R23.1, U3.36 (SH_C); also elsewhere on the board
/Power MOSFETS/Q6-s: U3.34 (SL_C); also elsewhere on the board
GND: C1.1, C8.1, C9.1, C18.2, C19.1, C20.1, C21.1, C23.1, C24.2, C25.2, C26.2, C33.2, C37.1, C39.1, C40.1, C42.2, C43.2, C44.2, C45.2, C46.2, C49.2, C51.1, C52.1, D4.2 (A), D5.1 (A), R18.2, R20.2, R21.1, R24.1, R25.1, R27.1, R33.1, U2.1 (GND), U3.8 (M_PWM), U3.10 (GAIN), U3.28 (AGND), U3.39 (SL_B), U3.57 (GND(POWER_PAD)); also elsewhere on the board
unnamed: C21.2, R19.1
unnamed: C27.1, D4.1 (K), L1.1, U3.50 (PH), U3.51 (PH)
unnamed: C23.2, U3.27 (AVDD)
unnamed: R25.2, U3.49 (BIAS)
unnamed: C28.2, U3.48 (BST_A)
unnamed: C29.2, U3.43 (BST_B)
unnamed: C27.2, U3.52 (BST_BK)
unnamed: C30.2, U3.38 (BST_C)
unnamed: C19.2, R19.2, U3.2 (COMP)
unnamed: C22.1, U3.14 (CP1)
unnamed: C22.2, U3.15 (CP2)
unnamed: R20.1, U3.7 (DTC)
unnamed: C20.2, C52.2, U3.11 (OC_ADJ), U3.23 (DVDD)
unnamed: C18.1, C26.1, U3.13 (GVDD)
unnamed: R21.2, U3.1 (RT_CLK)
unnamed: C34.1, R48.2, U3.33 (SN1)
unnamed: C36.1, R50.2, U3.31 (SN2)
unnamed: C34.2, R49.2, U3.32 (SP1)
unnamed: C36.2, R51.2, U3.30 (SP2)
unnamed: R17.2, R18.1, U3.3 (VSENSE)
VCC: C24.1, C25.1, U2.2 (VOUT), U2.4 (VOUT), U3.9 (M_OC); also elsewhere on the board
VDDA: U3.24 (REF); also elsewhere on the board
V_SUPPLY: C1.2, C8.2, C9.2, C37.2, C39.2, C40.2, C42.1, C43.1, C44.1, C45.1, C46.1, C49.1, C51.2, U3.29 (PVDD1), U3.53 (PVDD2), U3.54 (PVDD2); also elsewhere on the board

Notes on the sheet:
MCU must sense the voltage at each phase
3.3v regulator for the logic

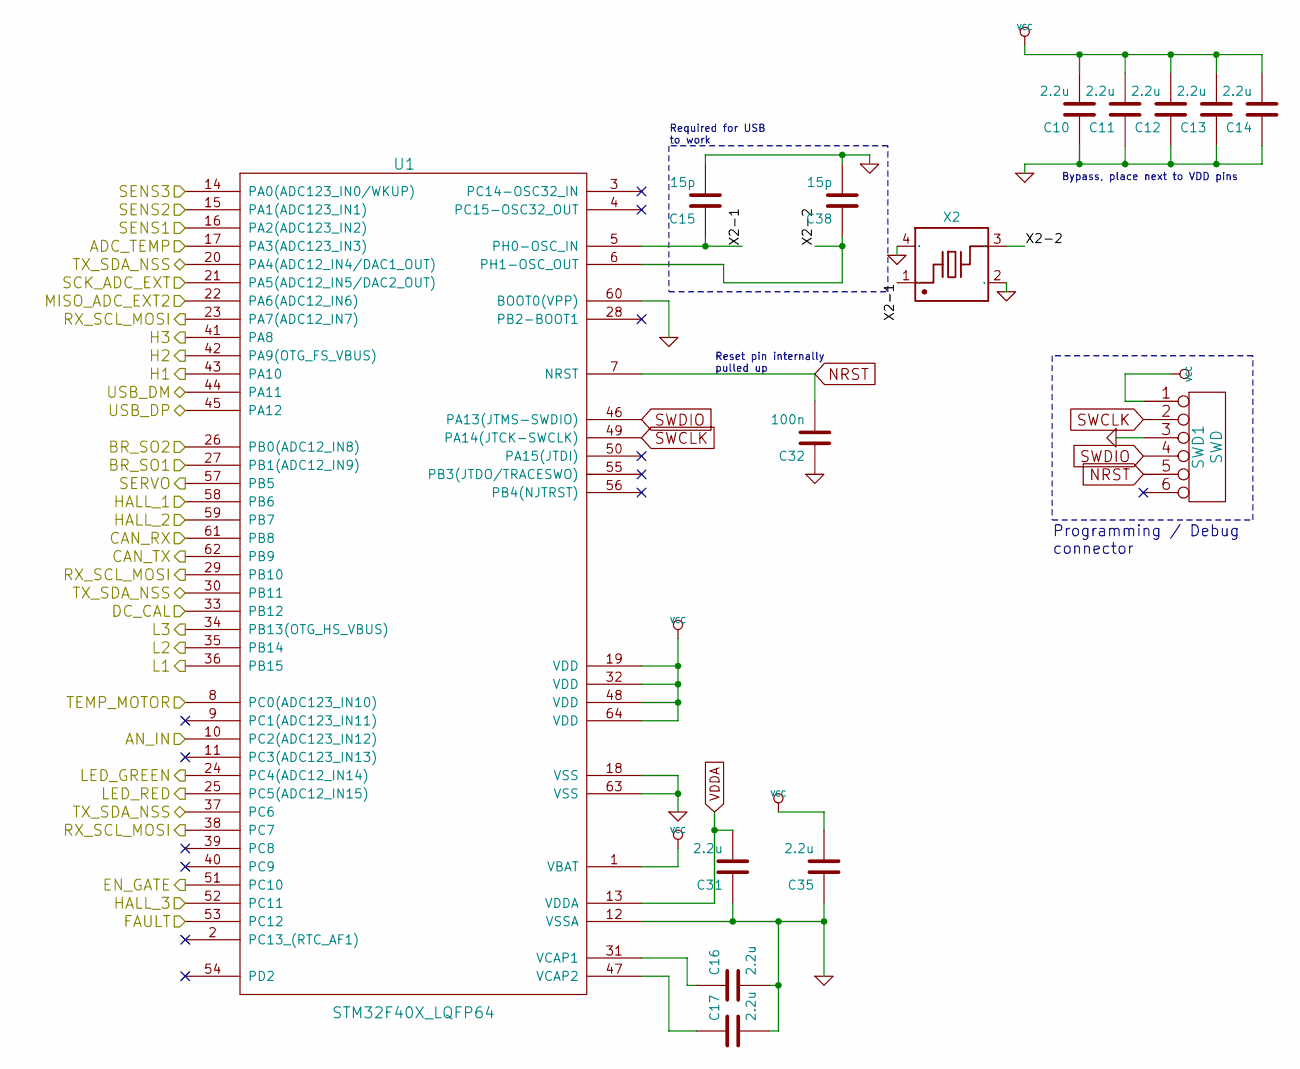
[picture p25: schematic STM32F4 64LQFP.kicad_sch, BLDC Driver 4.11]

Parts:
C10, C11, C12, C13, C14, C16, C17, C31, C35: 2.2u; C0603; LCSC C23630
C15, C38: 15p; C0603; LCSC C1644
C32: 100n; C0603; LCSC C14663
SWD1: SWD; CONN-TH_B6B-PH-K-S
U1: STM32F40X_LQFP64; lqfp64_pad_mod; LCSC C15742
X2: 5TJ480000NYLBC; CRYSTAL-SMD_4P-L5.0-W3.2-BL; Manufacturer Part 5TJ480000NYLBC; LCSC C2149245

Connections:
/ADC1_f: U1.21 (PA5(ADC12_IN5/DAC2_OUT)); also elsewhere on the board
/CAN bus transceiver/CAN_RX: U1.61 (PB8); also elsewhere on the board
/CAN bus transceiver/CAN_TX: U1.62 (PB9); also elsewhere on the board
/Filters/HALL1_OUT: U1.58 (PB6); also elsewhere on the board
/Filters/HALL2_OUT: U1.59 (PB7); also elsewhere on the board
/Filters/HALL3_OUT: U1.52 (PC11); also elsewhere on the board
/Filters/TEMP_MOTOR: U1.8 (PC0(ADC123_IN10)); also elsewhere on the board
/MCU/ADC_TEMP: U1.17 (PA3(ADC123_IN3)); also elsewhere on the board
/MCU/AN_IN: U1.10 (PC2(ADC123_IN12)); also elsewhere on the board
/MCU/BR_SO1: U1.27 (PB1(ADC12_IN9)); also elsewhere on the board
/MCU/BR_SO2: U1.26 (PB0(ADC12_IN8)); also elsewhere on the board
/MCU/DC_CAL: U1.33 (PB12); also elsewhere on the board
/MCU/EN_GATE: U1.51 (PC10); also elsewhere on the board
/MCU/FAULT: U1.53 (PC12); also elsewhere on the board
/MCU/H1: U1.43 (PA10); also elsewhere on the board
/MCU/H2: U1.42 (PA9(OTG_FS_VBUS)); also elsewhere on the board
/MCU/H3: U1.41 (PA8); also elsewhere on the board
/MCU/L1: U1.36 (PB15); also elsewhere on the board
/MCU/L2: U1.35 (PB14); also elsewhere on the board
/MCU/L3: U1.34 (PB13(OTG_HS_VBUS)); also elsewhere on the board
/MCU/LED_GREEN: U1.24 (PC4(ADC12_IN14)); also elsewhere on the board
/MCU/LED_RED: U1.25 (PC5(ADC12_IN15)); also elsewhere on the board
/MCU/SENS1: U1.16 (PA2(ADC123_IN2)); also elsewhere on the board
/MCU/SENS2: U1.15 (PA1(ADC123_IN1)); also elsewhere on the board
/MCU/SENS3: U1.14 (PA0(ADC123_IN0/WKUP)); also elsewhere on the board
/MCU/SERVO: U1.57 (PB5); also elsewhere on the board
/MCU/X2-1: C15.1, U1.5 (PH0-OSC_IN), X2.1
/MCU/X2-2: C38.1, U1.6 (PH1-OSC_OUT), X2.3
/MISO_RX_SCL: U1.22 (PA6(ADC12_IN6)); also elsewhere on the board
/RX_SCL_MOSI: U1.23 (PA7(ADC12_IN7)), U1.29 (PB10), U1.38 (PC7); also elsewhere on the board
/TX_SDA: U1.20 (PA4(ADC12_IN4/DAC1_OUT)), U1.30 (PB11), U1.37 (PC6); also elsewhere on the board
/USB+: U1.45 (PA12); also elsewhere on the board
/USB-: U1.44 (PA11); also elsewhere on the board
GND: C10.1, C11.1, C12.1, C13.1, C14.1, C15.2, C16.2, C17.2, C31.1, C32.1, C35.1, C38.2, SWD1.3, U1.12 (VSSA), U1.18 (VSS), U1.60 (BOOT0(VPP)), U1.63 (VSS), X2.2 (GND), X2.4 (GND); also elsewhere on the board
NRST: C32.2, SWD1.5, U1.7 (NRST)
unnamed: C16.1, U1.31 (VCAP1)
unnamed: C17.1, U1.47 (VCAP2)
SWCLK: SWD1.2, U1.49 (PA14(JTCK-SWCLK))
SWDIO: SWD1.4, U1.46 (PA13(JTMS-SWDIO))
VCC: C10.2, C11.2, C12.2, C13.2, C14.2, C35.2, SWD1.1, U1.1 (VBAT), U1.19 (VDD), U1.32 (VDD), U1.48 (VDD), U1.64 (VDD); also elsewhere on the board
VDDA: C31.2, U1.13 (VDDA); also elsewhere on the board

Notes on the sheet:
Required for USB to work
Programming / Debug connector
Reset pin internally pulled up
Bypass, place next to VDD pins

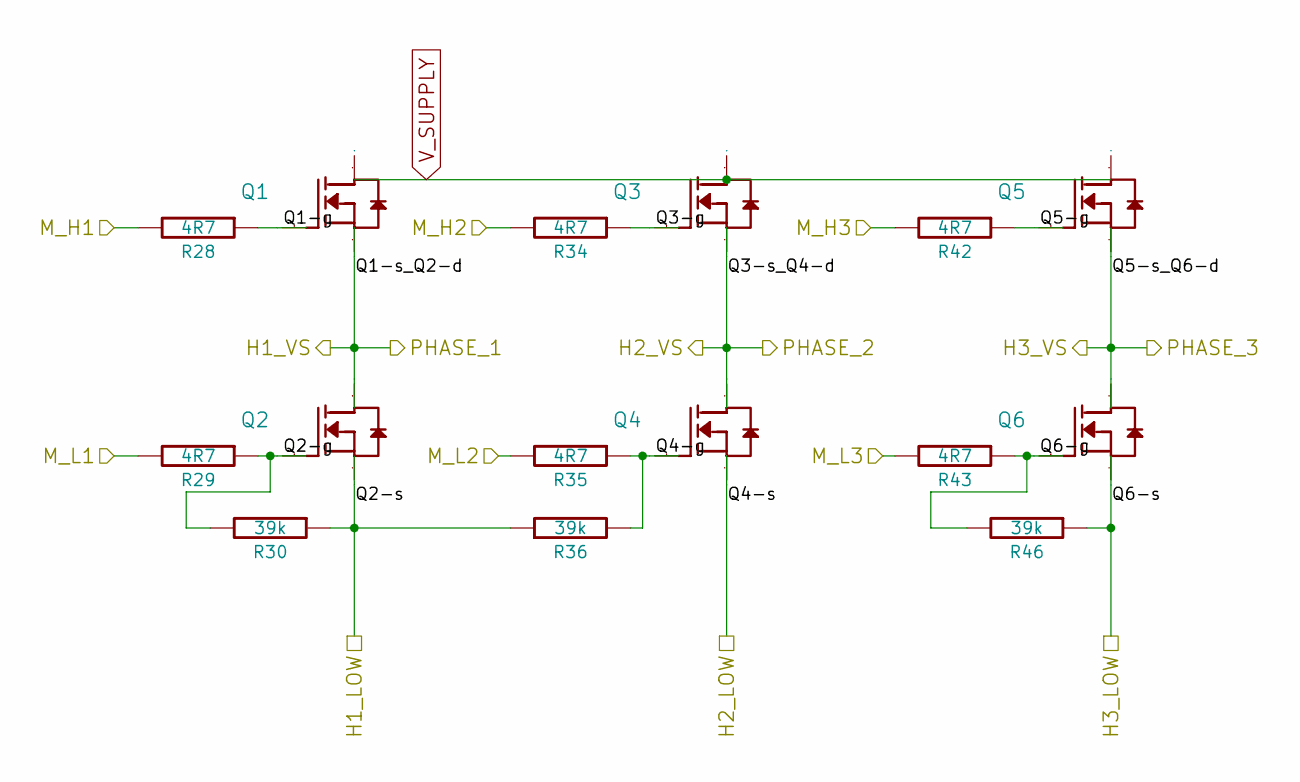
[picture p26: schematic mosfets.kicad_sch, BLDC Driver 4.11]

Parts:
Q1, Q2, Q3, Q4, Q5, Q6: IPT007N06NATMA1; HSOF-8_IPT007N06N; Manufacturer Part IPT007N06N; JLC_3DModel d50c126f5a2e4e8bb54a6100075e72a7
R28, R29, R34, R35, R42, R43: 4R7; R0603; JLC_3DModel 6bd5cd867e9542ebae21caaf5d2d4c4d
R30, R36, R46: 39k; R0603; JLC_3DModel 6bd5cd867e9542ebae21caaf5d2d4c4d

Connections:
/Mosfet driver/M_H1: R28.2; also elsewhere on the board
/Mosfet driver/M_H2: R34.2; also elsewhere on the board
/Mosfet driver/M_H3: R42.2; also elsewhere on the board
/Mosfet driver/M_L1: R29.2; also elsewhere on the board
/Mosfet driver/M_L2: R35.2; also elsewhere on the board
/Mosfet driver/M_L3: R43.2; also elsewhere on the board
/Power MOSFETS/Q1-g: Q1.1 (G), R28.1
/Power MOSFETS/Q1-s_Q2-d: Q1.2 (S), Q2.3 (D); also elsewhere on the board
/Power MOSFETS/Q2-g: Q2.1 (G), R29.1, R30.2
/Power MOSFETS/Q2-s: Q2.2 (S), R30.1, R36.1; also elsewhere on the board
/Power MOSFETS/Q3-g: Q3.1 (G), R34.1
/Power MOSFETS/Q3-s_Q4-d: Q3.2 (S), Q4.3 (D); also elsewhere on the board
/Power MOSFETS/Q4-g: Q4.1 (G), R35.1, R36.2
/Power MOSFETS/Q5-g: Q5.1 (G), R42.1
/Power MOSFETS/Q5-s_Q6-d: Q5.2 (S), Q6.3 (D); also elsewhere on the board
/Power MOSFETS/Q6-g: Q6.1 (G), R43.1, R46.2
/Power MOSFETS/Q6-s: Q6.2 (S), R46.1; also elsewhere on the board
GND: Q4.2 (S); also elsewhere on the board
V_SUPPLY: Q1.3 (D), Q3.3 (D), Q5.3 (D); also elsewhere on the board

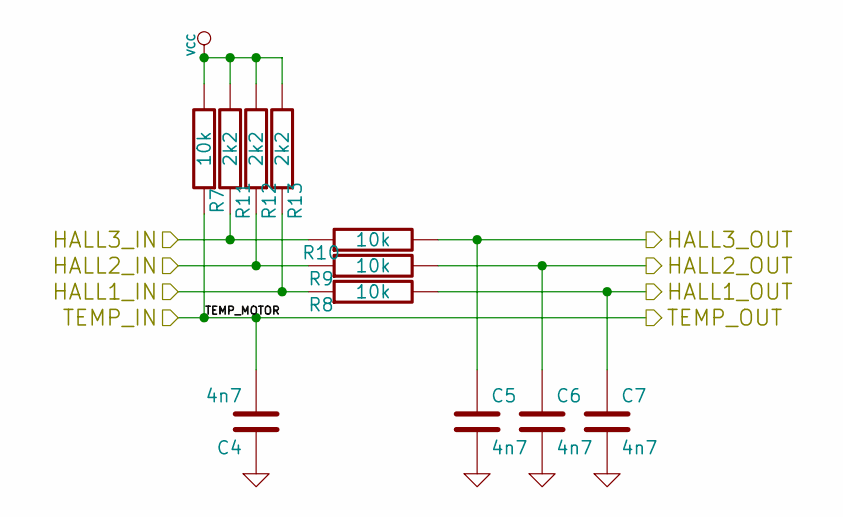
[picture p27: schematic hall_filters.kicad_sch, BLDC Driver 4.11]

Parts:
C4, C5, C6, C7: 4n7; C0603; LCSC C53987
R7, R8, R9, R10: 10k; R0603; JLC_3DModel 6bd5cd867e9542ebae21caaf5d2d4c4d
R11, R13: 2k2; R0603; JLC_3DModel 6bd5cd867e9542ebae21caaf5d2d4c4d
R12: 2k2; R0603; LCSC C4190

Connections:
/Filters/HALL1_IN: R8.1, R13.1; also elsewhere on the board
/Filters/HALL1_OUT: C7.1, R8.2; also elsewhere on the board
/Filters/HALL2_IN: R9.1, R12.1; also elsewhere on the board
/Filters/HALL2_OUT: C6.1, R9.2; also elsewhere on the board
/Filters/HALL3_IN: R10.1, R11.1; also elsewhere on the board
/Filters/HALL3_OUT: C5.1, R10.2; also elsewhere on the board
/Filters/TEMP_MOTOR: C4.2, R7.1; also elsewhere on the board
GND: C4.1, C5.2, C6.2, C7.2; also elsewhere on the board
VCC: R7.2, R11.2, R12.2, R13.2; also elsewhere on the board

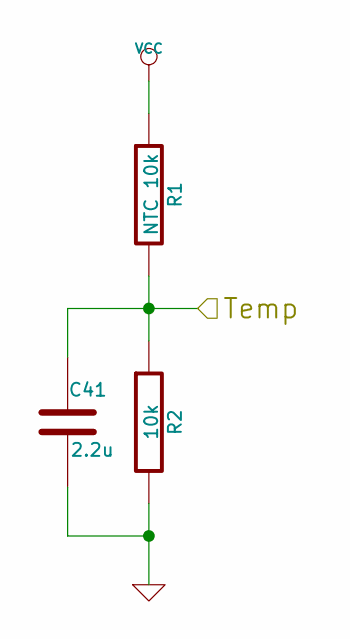
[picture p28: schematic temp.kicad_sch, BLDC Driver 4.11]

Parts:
C41: 2.2u; C0603; JLC_3DModel ac9b32e974bc448eab36b1293f859dcb
R1: NTC 10k; R0603; JLC_3DModel 6bd5cd867e9542ebae21caaf5d2d4c4d
R2: 10k; R0603; JLC_3DModel 6bd5cd867e9542ebae21caaf5d2d4c4d

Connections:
/MCU/ADC_TEMP: C41.1, R1.2, R2.1; also elsewhere on the board
GND: C41.2, R2.2; also elsewhere on the board
VCC: R1.1; also elsewhere on the board

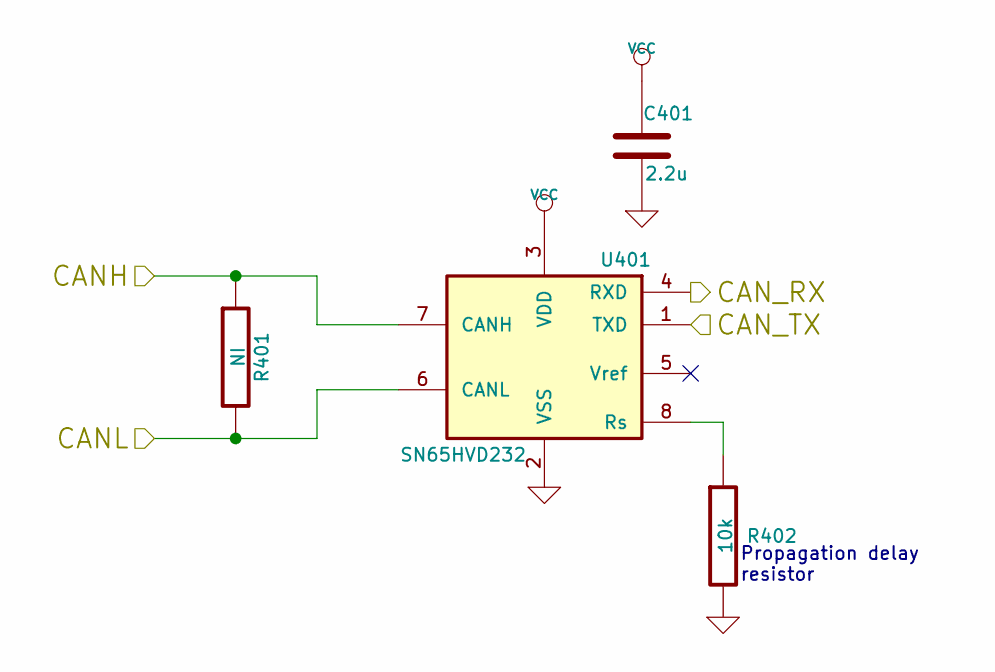
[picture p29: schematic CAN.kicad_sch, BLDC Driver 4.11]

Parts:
C401: 2.2u; C0603; LCSC C23630
R401: NI; R0603; JLC_3DModel 6bd5cd867e9542ebae21caaf5d2d4c4d
R402: 10k; R0603; LCSC C25804
U401: SN65HVD232; SOIC-8-W; LCSC C46596301

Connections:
/CAN bus transceiver/CANH: R401.1, U401.7 (CANH); also elsewhere on the board
/CAN bus transceiver/CANL: R401.2, U401.6 (CANL); also elsewhere on the board
/CAN bus transceiver/CAN_RX: U401.4 (RXD); also elsewhere on the board
/CAN bus transceiver/CAN_TX: U401.1 (TXD); also elsewhere on the board
GND: C401.2, R402.2, U401.2 (VSS); also elsewhere on the board
unnamed: R402.1, U401.8 (Rs)
VCC: C401.1, U401.3 (VDD); also elsewhere on the board

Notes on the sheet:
Propagation delay resistor

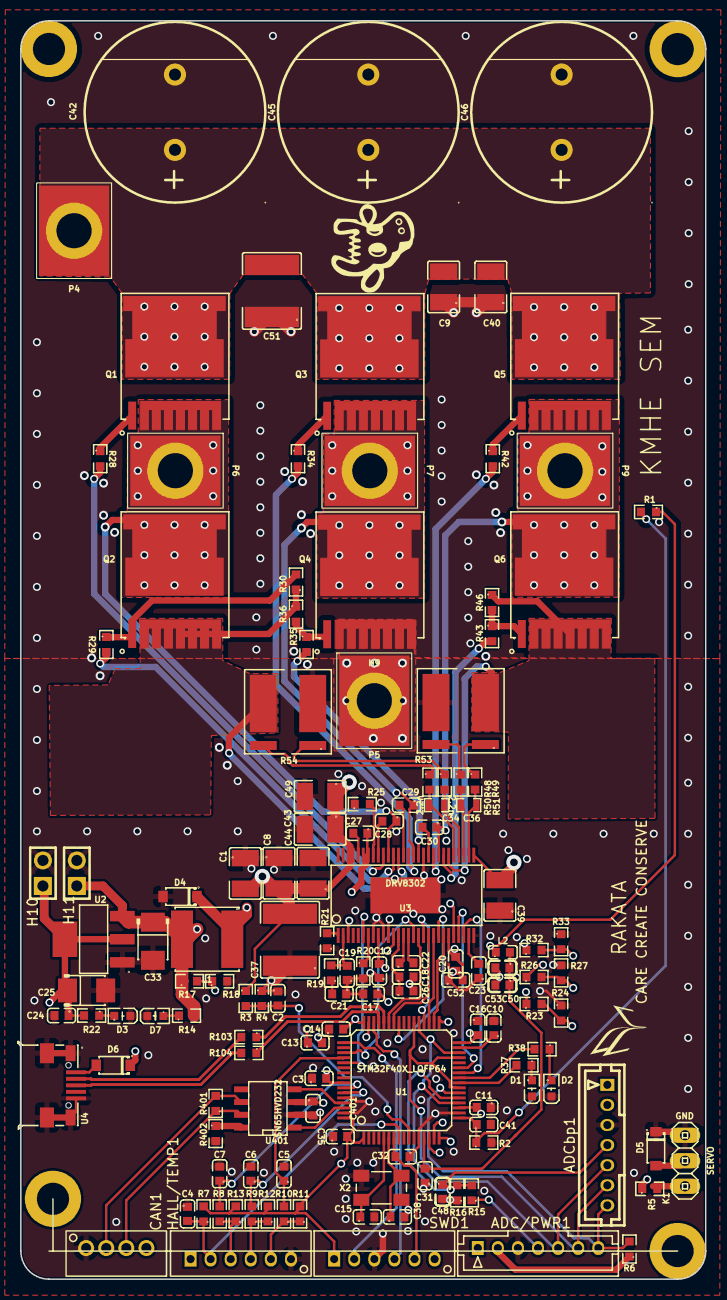
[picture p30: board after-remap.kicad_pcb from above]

Board: 4 copper layers, 68.2 x 125.3 mm, 146 parts (0 on the bottom side), 99 nets.

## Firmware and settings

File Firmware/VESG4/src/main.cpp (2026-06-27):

#include <Arduino.h>
#include <SimpleFOC.h>
#include "board_config.h"
#include "motor_config.h"
#include "drv8302.h"
#include "helpers.h"

// System clock initialization sequence tailored to VESC 4's 8MHz crystal architecture
extern "C" void SystemClock_Config(void) {
    RCC_OscInitTypeDef RCC_OscInitStruct = {0};
    RCC_ClkInitTypeDef RCC_ClkInitStruct = {0};

    __HAL_RCC_PWR_CLK_ENABLE();
    __HAL_PWR_VOLTAGESCALING_CONFIG(PWR_REGULATOR_VOLTAGE_SCALE1);

    RCC_OscInitStruct.OscillatorType = RCC_OSCILLATORTYPE_HSE;
    RCC_OscInitStruct.HSEState = RCC_HSE_ON;
    RCC_OscInitStruct.PLL.PLLState = RCC_PLL_ON;
    RCC_OscInitStruct.PLL.PLLSource = RCC_PLLSOURCE_HSE;
    RCC_OscInitStruct.PLL.PLLM = 8;
    RCC_OscInitStruct.PLL.PLLN = 336;
    RCC_OscInitStruct.PLL.PLLP = RCC_PLLP_DIV2;
    RCC_OscInitStruct.PLL.PLLQ = 7;
    if (HAL_RCC_OscConfig(&RCC_OscInitStruct) != HAL_OK) { Error_Handler(); }

    RCC_ClkInitStruct.ClockType = RCC_CLOCKTYPE_HCLK|RCC_CLOCKTYPE_SYSCLK|RCC_CLOCKTYPE_PCLK1|RCC_CLOCKTYPE_PCLK2;
    RCC_ClkInitStruct.SYSCLKSource = RCC_SYSCLKSOURCE_PLLCLK;
    RCC_ClkInitStruct.AHBCLKDivider = RCC_SYSCLK_DIV1;
    RCC_ClkInitStruct.APB1CLKDivider = RCC_HCLK_DIV4;
    RCC_ClkInitStruct.APB2CLKDivider = RCC_HCLK_DIV2;

    if (HAL_RCC_ClockConfig(&RCC_ClkInitStruct, FLASH_LATENCY_5) != HAL_OK) { Error_Handler(); }
}

void jumpToSystemBootloader();

DRV8302 drv(PIN_EN_GATE, PIN_DCCAL, PIN_DRV_FAULT);

BLDCMotor motor = BLDCMotor(MOTOR_POLE_PAIRS);
BLDCDriver6PWM driver = BLDCDriver6PWM(PWM_AH, PWM_AL, PWM_BH, PWM_BL, PWM_CH, PWM_CL, EN_GATE);

HallSensor sensor = HallSensor(PIN_HALL_A, PIN_HALL_B, PIN_HALL_C, MOTOR_POLE_PAIRS);
LowsideCurrentSense current_sense = LowsideCurrentSense(CURRENT_SHUNT_RES, CURRENT_AMP_GAIN, PIN_CURR_A, _NC, PIN_CURR_C);

// Global flags configuration profiles
float target_current = 0.0f;
bool deadman_bypass = true;
bool drv_fault_bypass = true; // Set to true for automated high-speed latch resetting

void doA() { sensor.handleA(); }
void doB() { sensor.handleB(); }
void doC() { sensor.handleC(); }

void setup() {
    Serial.begin(115200);
    SimpleFOCDebug::enable(&Serial);
    
    pinMode(PIN_DEADMAN, INPUT); 
    pinMode(PIN_LED_RED, OUTPUT);
    pinMode(PIN_LED_GREEN, OUTPUT);
    
    digitalWrite(PIN_LED_RED, HIGH); 

    // ============================ POWER
    uint32_t timeout = millis();
    while (!Serial && (millis() - timeout < 3000)) { delay(10); }
    Serial.println("USB Serial connected. Initializing hardware...");

    analogReadResolution(12);
    driver.voltage_power_supply = readBatteryVoltage();
    driver.voltage_limit = DRIVER_VOLTAGE_LIMIT;
    Serial.print("Detected Power Supply Voltage: ");
    Serial.println(readBatteryVoltage());

    Serial.println("Waiting for High Voltage power supply...");
    while (readBatteryVoltage() < 8.0f) {
        digitalWrite(PIN_LED_RED, !digitalRead(PIN_LED_RED)); 
        delay(250); 
    }

    Serial.println("SUCCESS: High Voltage detected.");
    digitalWrite(PIN_LED_RED, LOW);

    // ============================

    drv.init();
    drv.disableGate(); 
    delay(50);
    drv.enableGate();
    delay(100);

    if (drv.isFaulted()) {
        Serial.println("CRITICAL: Power is ON, but DRV is throwing a hard fault at boot. Halting.");
        digitalWrite(PIN_LED_RED, HIGH);
        while(1) { delay(1000); }
    }
    
    sensor.pullup = Pullup::USE_EXTERN; 
    sensor.init();
    sensor.enableInterrupts(doA, doB, doC);
    motor.linkSensor(&sensor);

    driver.pwm_frequency = FOC_PWM_FREQ; 
    driver.dead_zone = 0.05f; 
    
    if (!driver.init()) {
        Serial.println("CRITICAL: Driver 6-PWM failed to initialize!");
        digitalWrite(PIN_LED_RED, HIGH);
        while(1) { delay(100); }
    }
    motor.linkDriver(&driver);

    // --- AUTOMATED VESC DC CURRENT AMPLIFIER CALIBRATION ---
    Serial.println("Enabling DRV8302 internal DC amplifier calibration...");
    digitalWrite(PIN_DCCAL, HIGH); 
    delay(50);                    

    current_sense.linkDriver(&driver);
    if (!current_sense.init()) {
        Serial.println("CRITICAL: Low-side current sense failed!");
        digitalWrite(PIN_DCCAL, LOW); 
        digitalWrite(PIN_LED_RED, HIGH);
        while(1) { delay(100); }
    }
    
    digitalWrite(PIN_DCCAL, LOW);  
    delay(10);                     
    motor.linkCurrentSense(&current_sense);

    // --- FOC PARAMS SETUP ---
    motor.controller = MotionControlType::torque;
    motor.torque_controller = TorqueControlType::foc_current;
    motor.current_limit = MOTOR_CURRENT_LIMIT;
    motor.voltage_sensor_align = 1.4f; // Optimal alignment setting for 12V 3A tracking
    
    // Low-resistance motor PID tuned parameters
    motor.PID_current_q.P = 0.015f; 
    motor.PID_current_d.P = 0.015f;
    motor.PID_current_q.I = 1.0f;   
    motor.PID_current_d.I = 1.0f;
    motor.PID_current_q.output_ramp = 1000.0f; 
    motor.PID_current_d.output_ramp = 1000.0f;
    
    motor.monitor_downsample = 100;
    motor.useMonitoring(Serial);
    
    motor.init();
    
    Serial.println("Starting FOC Alignment...");
    motor.initFOC(); 

    Serial.println("Setup complete. Ready for commands.");
}

void loop() {
    static uint32_t fault_start_time = 0;

    if (drv.isFaulted()) {
        if (fault_start_time == 0) {
            fault_start_time = millis();
        } 
        else if (millis() - fault_start_time > 10) { 
            if (drv_fault_bypass) {
                // High-speed auto-recovery clearing loop
                drv.disableGate();
                delayMicroseconds(5); 
                drv.enableGate();
                fault_start_time = 0; 
                Serial.println("BYPASS NOTICE: Transient noise or gate spike cleared from DRV. Resuming loop.");
            } 
            else {
                digitalWrite(PIN_LED_RED, HIGH); 
                drv.disableGate();
                motor.move(0.0f); 
                
                if (readBatteryVoltage() < 10.0f) {
                    Serial.println("Power loss detected. Going to sleep...");
                    while (readBatteryVoltage() < 10.0f) {
                        digitalWrite(PIN_LED_RED, !digitalRead(PIN_LED_RED));
                        delay(500);
                    }
                    Serial.println("Power restored. Rebooting STM32...");
                    delay(100);
                    NVIC_SystemReset();
                }

                Serial.println("DRV SUSTAINED FAULT DETECTED - Attempting recovery...");
                delay(500); 
                drv.enableGate();
                delay(10);
                
                if (drv.isFaulted()) {
                    Serial.println("CRITICAL: Fault persists. Halting.");
                    digitalWrite(PIN_LED_RED, HIGH);
                    while (1) { delay(1000); } 
                } else {
                    digitalWrite(PIN_LED_RED, LOW); 
                    Serial.println("Recovery successful. Resuming normal operation.");
                    fault_start_time = 0;
                }
            }
        }
    } 
    else {
        fault_start_time = 0;
    }

    if (!deadmanPressed() && !deadman_bypass) {
        target_current = 0.0f;
        motor.move(0); 
        motor.loopFOC(); 
        return; 
    }

    static int loop_count = 0;
    if (loop_count++ > 100) {
        driver.voltage_power_supply = readBatteryVoltage();
        loop_count = 0;
    }

    // Intercept serial instruction tokens before numerical parsers
    if (Serial.available() > 0) {
        char peek_char = Serial.peek();
        if ((peek_char >= 'a' && peek_char <= 'z') || (peek_char >= 'A' && peek_char <= 'Z')) {
            String cmd = Serial.readStringUntil('\n');
            cmd.trim();
            if (cmd.equalsIgnoreCase("DFU") || cmd.equalsIgnoreCase("RESET")) {
                drv.disableGate(); 
                jumpToSystemBootloader();
            }
        }
    }

    readSerialTarget();

    if (abs(target_current) > 0.05f) {
        digitalWrite(PIN_LED_GREEN, HIGH);
    } else {
        if ((millis() / 500) % 2 == 0) {
            digitalWrite(PIN_LED_GREEN, HIGH);
        } else {
            digitalWrite(PIN_LED_GREEN, LOW);
        }
    }

    motor.loopFOC();
    motor.move(target_current);
}

// FLASH MENGGUNAKAN USB BELUM BERHASIL DIPAKE
void jumpToSystemBootloader() {
    Serial.println("Executing Software Jump to Native USB DFU Mode...");
    delay(100);
    
    __disable_irq();
    
    SysTick->CTRL = 0;
    SysTick->LOAD = 0;
    SysTick->VAL = 0;

    for (int i = 0; i < 8; i++) {
        NVIC->ICER[i] = 0xFFFFFFFF;
        NVIC->ICPR[i] = 0xFFFFFFFF;
    }

    __HAL_RCC_SYSCFG_CLK_ENABLE();
    SYSCFG->MEMRMP = 0x01; 

    uint32_t dfu_address = 0x1FFF0000;
    uint32_t jump_address = *(__IO uint32_t*)(dfu_address + 4);
    void (*JumpToApplication)(void) = (void (*)(void))jump_address;
    
    __set_MSP(*(__IO uint32_t*)dfu_address);
    JumpToApplication();
    while(1); 
}

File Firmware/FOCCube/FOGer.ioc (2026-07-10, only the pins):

Mcu.UserName=STM32F405RGTx
PA10.Signal=S_TIM1_CH3
PA11.Signal=USB_OTG_FS_DM
PA12.Signal=USB_OTG_FS_DP
PA13.Signal=SYS_JTMS-SWDIO
PA14.Signal=SYS_JTCK-SWCLK
PA5.Signal=ADCx_IN5
PA6.GPIO_Label=DEADMAN
PA6.Signal=GPIO_Input
PA8.Signal=S_TIM1_CH1
PA9.Signal=S_TIM1_CH2
PB0.Signal=ADCx_IN8
PB1.Signal=ADCx_IN9
PB12.GPIO_Label=DC_CAL
PB12.Signal=GPIO_Output
PB13.Signal=TIM1_CH1N
PB14.Signal=TIM1_CH2N
PB15.Signal=TIM1_CH3N
PB6.Signal=GPXTI6
PB7.Signal=GPXTI7
PC10.GPIO_Label=EN_GATE
PC10.Signal=GPIO_Output
PC11.Signal=GPXTI11
PC12.GPIO_Label=DRV_FAULT
PC12.Signal=GPXTI12
PC2.Signal=ADCx_IN12
PC4.GPIO_Label=LED_GREEN
PC4.Signal=GPIO_Output
PC5.GPIO_Label=LED_RED
PC5.Signal=GPIO_Output
PH0-OSC_IN.Signal=RCC_OSC_IN
PH1-OSC_OUT.Signal=RCC_OSC_OUT

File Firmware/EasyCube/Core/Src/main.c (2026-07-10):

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
/* Includes ------------------------------------------------------------------*/
#include "main.h"
#include "usb_device.h"

/* USER CODE BEGIN Includes */
#include "main.h"
#include "usb_device.h"
#include "usbd_cdc_if.h"
#include <stdio.h>
/* USER CODE END Includes */

ADC_HandleTypeDef hadc1;

TIM_HandleTypeDef htim1;

/* USER CODE BEGIN PV */
volatile uint8_t usb_throttle_target = 0;
const uint8_t hallToMotor[8] = {255, 1, 3, 2, 5, 6, 4, 255};

uint32_t lastDebugPrint = 0;
uint32_t faultResetCount = 0;
float v_bat = 0.0f;
uint16_t raw_throttle = 0;

// Variables to catch the hardware-synced ADC readings
volatile uint16_t current_phase_A = 0;
volatile uint16_t current_phase_C = 0;
/* USER CODE END PV */

void SystemClock_Config(void);
static void MX_GPIO_Init(void);
static void MX_ADC1_Init(void);
static void MX_TIM1_Init(void);
/* USER CODE BEGIN PFP */
void Commutate(uint8_t state, uint16_t throttle);
/* USER CODE END PFP */

/* USER CODE BEGIN 0 */


// Retarget standard library printf to the USB CDC interface safely
int _write(int file, char *ptr, int len) {
    uint32_t timeout = 500000; // Failsafe timeout to prevent locking the MCU

    // Wait until the USB interface is no longer BUSY
    while (CDC_Transmit_FS((uint8_t*)ptr, len) == USBD_BUSY && timeout-- > 0) {
        // Do nothing, just wait
    }
    return len;
}
/* USER CODE END 0 */

/**
  * @brief  The application entry point.
  * @retval int
  */
int main(void)
{

  /* MCU Configuration--------------------------------------------------------*/

  /* Reset of all peripherals, Initializes the Flash interface and the Systick. */
  HAL_Init();

  /* Configure the system clock */
  SystemClock_Config();

  /* Initialize all configured peripherals */
  MX_GPIO_Init();
  MX_ADC1_Init();
  MX_TIM1_Init();
  MX_USB_DEVICE_Init();
  /* USER CODE BEGIN 2 */
  // Start the High-Side PWM channels
  HAL_TIM_PWM_Start(&htim1, TIM_CHANNEL_1); // Phase C
  HAL_TIM_PWM_Start(&htim1, TIM_CHANNEL_2); // Phase B
  HAL_TIM_PWM_Start(&htim1, TIM_CHANNEL_3); // Phase A

  // Start the Low-Side Complementary channels
  HAL_TIMEx_PWMN_Start(&htim1, TIM_CHANNEL_1);
  HAL_TIMEx_PWMN_Start(&htim1, TIM_CHANNEL_2);
  HAL_TIMEx_PWMN_Start(&htim1, TIM_CHANNEL_3);

  Commutate(0, 0);
  // 2. Start the Hardware-Synced Current Sensing
  HAL_ADCEx_InjectedStart_IT(&hadc1);

  setvbuf(stdout, NULL, _IONBF, 0); // Disable printf buffering
  // 3. Calibrate ADC & Check High Voltage
  printf("Waiting for High Voltage power supply...\r\n");
  do {
	HAL_ADC_Start(&hadc1);
	HAL_ADC_PollForConversion(&hadc1, 5);
	HAL_ADC_GetValue(&hadc1);             // <-- ADD THIS: Physically pulls data to clear EOC flag
	HAL_ADC_PollForConversion(&hadc1, 5);
	uint16_t raw_v = HAL_ADC_GetValue(&hadc1);
	v_bat = (raw_v / 4095.0f) * 3.3f * ((39000.0f + 2200.0f) / 2200.0f);
	HAL_Delay(100);
  } while (v_bat < 8.0f);

  printf("SUCCESS: High Voltage detected at %.2fV\r\n", v_bat);

  // 4. Enable the DRV8302 Gate Driver
  HAL_GPIO_WritePin(GPIOC, GPIO_PIN_10, GPIO_PIN_SET); // EN_GATE HIGH
  HAL_Delay(100);
  /* USER CODE END 2 */

  /* Infinite loop */
  /* USER CODE BEGIN WHILE */
  while (1)
  {
    /* USER CODE END WHILE */

    /* USER CODE BEGIN 3 */
	  // --- Kickstart & Instant-Stop Logic ---
	  static uint8_t active_throttle = 0;

	  if (usb_throttle_target > 0 && active_throttle == 0) {
		  // Kickstart: The motor is stopped. Read halls manually to fire the first commutation.
		  uint8_t hallA = (GPIOB->IDR & GPIO_PIN_6)  ? 1 : 0;
		  uint8_t hallB = (GPIOB->IDR & GPIO_PIN_7)  ? 1 : 0;
		  uint8_t hallC = (GPIOC->IDR & GPIO_PIN_11) ? 1 : 0;
		  uint8_t hall_val = hallA | (hallB << 1) | (hallC << 2);

		  Commutate(hallToMotor[hall_val], usb_throttle_target);
	  }
	  else if (usb_throttle_target == 0 && active_throttle > 0) {
		  // Instant Stop: Cut power immediately instead of waiting for a slow coasting interrupt
		  Commutate(0, 0);
	  }

	  active_throttle = usb_throttle_target; // Update the tracker
	  // ===== 1. Hardware Fault Check (DRV8302 Active-Low Fault) =====
	  if (HAL_GPIO_ReadPin(GPIOC, GPIO_PIN_12) == GPIO_PIN_RESET) {
		  faultResetCount++;

		  // --- ADD THESE TWO LINES FOR SAFETY ---
		  usb_throttle_target = 0; // Force user to manually throttle up again
		  Commutate(0, 0);         // Instantly disconnect all MOSFETs

		  HAL_GPIO_WritePin(GPIOC, GPIO_PIN_5, GPIO_PIN_SET); // LED_RED ON
		  printf("!!! DRV FAULT !!! Resetting EN_GATE. Throttle Zeroed.\r\n");

		  // Pulse EN_GATE low to clear latched faults
		  HAL_GPIO_WritePin(GPIOC, GPIO_PIN_10, GPIO_PIN_RESET);
		  HAL_Delay(1); // 1 ms guarantees a successful hardware latch clear
		  HAL_GPIO_WritePin(GPIOC, GPIO_PIN_10, GPIO_PIN_SET);
	  } else {
		  HAL_GPIO_WritePin(GPIOC, GPIO_PIN_5, GPIO_PIN_RESET); // LED_RED OFF
	  }

	  // ===== 2. Read Regular ADC (Throttle & Voltage) =====
	  HAL_ADC_Start(&hadc1);
	  if (HAL_ADC_PollForConversion(&hadc1, 5) == HAL_OK) {
		  raw_throttle = HAL_ADC_GetValue(&hadc1); // Rank 1: Throttle
	  }
	  if (HAL_ADC_PollForConversion(&hadc1, 5) == HAL_OK) {
		  uint16_t raw_v = HAL_ADC_GetValue(&hadc1); // Rank 2: Bus Voltage
		  v_bat = (raw_v / 4095.0f) * 3.3f * ((39000.0f + 2200.0f) / 2200.0f);
	  }

	  // Turn on Green LED if throttle is active (using your USB override variable)
	  HAL_GPIO_WritePin(GPIOC, GPIO_PIN_4, (usb_throttle_target > 0) ? GPIO_PIN_SET : GPIO_PIN_RESET);

	  // ===== 3. Telemetry Heartbeat (Non-blocking, 500ms) =====
	  if (HAL_GetTick() - lastDebugPrint >= 500) {
		  lastDebugPrint = HAL_GetTick();

		  printf("[DATA] Thr_Target: %d | IA_Raw: %d | IC_Raw: %d | Bus: %.2fV | Resets: %lu\r\n",
				  usb_throttle_target,
				  current_phase_A,
				  current_phase_C,
				  v_bat,
				  faultResetCount);
	  }
  }
  /* USER CODE END 3 */
}
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

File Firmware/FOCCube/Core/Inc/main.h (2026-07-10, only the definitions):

#define DEADMAN_Pin GPIO_PIN_6
#define DEADMAN_GPIO_Port GPIOA
#define LED_GREEN_Pin GPIO_PIN_4
#define LED_GREEN_GPIO_Port GPIOC
#define LED_RED_Pin GPIO_PIN_5
#define LED_RED_GPIO_Port GPIOC
#define DC_CAL_Pin GPIO_PIN_12
#define DC_CAL_GPIO_Port GPIOB
#define EN_GATE_Pin GPIO_PIN_10
#define EN_GATE_GPIO_Port GPIOC
#define DRV_FAULT_Pin GPIO_PIN_12
#define DRV_FAULT_GPIO_Port GPIOC
#define DRV_FAULT_EXTI_IRQn EXTI15_10_IRQn
#define POLE_PAIRS 8.0f

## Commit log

2026-04-20 added vesc-4 hardware
    [BLDC4.12_BOM.ods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]
2026-04-23 firmware ccllogging
    mau mulai improve algoritma PID
2026-04-24 revert
    This reverts commit 5363225a17d2aae300a7f308fe655f067ec562b7.
    [easyccllogging.ino]
2026-05-16 all done
    [CAN.kicad_sch, Power.kicad_sch, STM32F4 64LQFP.kicad_sch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]
2026-05-16 update mosfet
    [after-remap.kicad_pcb, mosfets.kicad_sch]
2026-05-16 fix conn
    [after-remap.kicad_pcb]
2026-05-18 chekcpoint 18 mei
    [CAN.kicad_sch, Power.kicad_sch, STM32F4 64LQFP.kicad_sch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]
2026-05-18 fixed alignment and orientation
    [after-remap-CuBottom.gbr, after-remap-CuIn1.gbr, after-remap-CuIn2.gbr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]

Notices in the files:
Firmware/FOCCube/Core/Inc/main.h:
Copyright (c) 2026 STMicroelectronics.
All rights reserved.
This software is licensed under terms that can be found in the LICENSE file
